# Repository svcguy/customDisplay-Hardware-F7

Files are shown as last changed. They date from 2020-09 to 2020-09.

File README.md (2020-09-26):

A custom display development PCB targeted to be compatible with STM32CubeMX and TouchGFX.  
Based on the STM32F767 MCU with 128Mbit external SDRAM, 512Mbit external QSPI flash.
PCB is designed to be compatible with JLCPCB's SMT service.

More to come!
Work in progress!

Changelog:
Rev A0 -    inital design.  Sent to fab
Rev B1 -    PCB changes -       move traces too close to PCB edge
                                change C23 footprint to 0805 (bom consolidation)
                                move some dimensions to B.Fab layer
            Schematic changes - change C23 footprint to 0805 (bom consolidation)
                                update some footprint properties to "virtual"
            General changes -   Generate PDF of schematic and top and bot assembly drawings

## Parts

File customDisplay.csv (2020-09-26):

Comment | Designator | Footprint | LCSC | Digikey | LCSC
0.1uF | C14,C25,C1,C2,C3,C4,C5,C6,C7,C8,C9,C15,C16,C17,C18,C19,C20,C21,C22,C10,C12,C33,C34,C35,C36,C37,C38,C39,C40,C41,C42,C43,C44,C46,C49,C51,C52 | jlcpcb_smt:C_0402_1005Metric |  | 1276-1004-1-ND | C1525
4.7uF | C23,C50 | jlcpcb_smt:C_0805_2012Metric |  | 490-10481-1-ND | C19666
1uF | C24,C11,C13,C32,C45 | jlcpcb_smt:C_0402_1005Metric |  | 490-10017-1-ND | C52923
2.2uF | C26,C27,C48,C47,C53,C54 | jlcpcb_smt:C_0603_1608Metric |  | 399-7886-1-ND | C23630
15pF | C28,C29 | jlcpcb_smt:C_0402_1005Metric |  | 399-8947-1-ND | C1548
30pF | C30,C31 | jlcpcb_smt:C_0402_1005Metric |  | 311-1666-1-ND | C1570
LED0 | D1 | jlcpcb_smt:LED_0603_1608Metric |  | 160-1447-1-ND | C2286
LED1 | D2 | jlcpcb_smt:LED_0603_1608Metric |  | 160-1448-1-ND | C72038
LED2 | D3 | jlcpcb_smt:LED_0603_1608Metric |  | 160-1446-1-ND | C72043
B5819W | D4 | Diode_SMD:D_SOD-123 |  | B5819W-TPMSCT-ND | C8598
Fiducial | FID1,FID2,FID3,FID4,FID5 | Fiducial:Fiducial_1mm_Mask2mm |  | DNP | DNP
4-40 | H1,H2,H3,H4 | MountingHole:MountingHole_3.2mm_M3 |  | DNP | DNP
STDC14 | J1 | Custom_KICAD:STDC14_BOX |  | 1175-1630-ND | DNP
B2B_TOP | J3,J2 | Custom_KICAD:FX6A-040P-0.8SV |  | H123465-ND | DNP
LCD | J4 | Custom_KICAD:FH12A-40S-0.5SH_REVERSE_PIN_NUMBERING |  | HFK140CT-ND | C262686
TOUCH | J5 | Connector_FFC-FPC:Hirose_FH12-6S-0.5SH_1x06-1MP_P0.50mm_Horizontal |  | HFJ106CT-ND | C262287
USB_B_Micro | J6 | Connector_USB:USB_Micro-B_Amphenol_10103594-0001LF_Horizontal |  | 609-4050-1-ND | C428495
5V_IN | J7 | Connector_PinHeader_2.54mm:PinHeader_1x02_P2.54mm_Vertical |  | DNP | DNP
STDC14_TAG | J8 | Connector:Tag-Connect_TC2070-IDC-FP_2x07_P1.27mm_Vertical |  | DNP | DNP
BEAD | L1,L2,L4 | jlcpcb_smt:L_0805_2012Metric |  | 587-1932-1-ND | C1015
4.7uH | L3 | Custom_KICAD:MWSA0402 |  | 490-10858-1-ND | C408337
COMMON_MODE | L5 | jlcpcb_smt:COMMON_MODE_FILTER_0805 |  | 490-5137-1-ND | C54888
220 | R1,R2,R3 | jlcpcb_smt:R_0402_1005Metric |  | 311-220LRCT-ND | C25091
10k | R5,R4,R10 | jlcpcb_smt:R_0402_1005Metric |  | 311-10.0KLRCT-ND | C25744
4.7k | R6,R7 | jlcpcb_smt:R_0402_1005Metric |  | 311-4.7KLRCT-ND | C25900
10R | R8,R9 | jlcpcb_smt:R_1206_3216Metric |  | RNCP1206FTD10R0CT-ND | C17903
TACT | SW2,SW1 | jlcpcb_smt:TS_1187A |  | 450-2133-1-ND | C318889
ToolingHole | TH1,TH2,TH3 | jlcpcb_smt:JLC_TOOLING_HOLE |  | DNP | DNP
VCP_RX | TP1 | TestPoint:TestPoint_THTPad_1.0x1.0mm_Drill0.5mm |  | DNP | DNP
VCP_TX | TP2 | TestPoint:TestPoint_THTPad_1.0x1.0mm_Drill0.5mm |  | DNP | DNP
I2C_SDA | TP3 | TestPoint:TestPoint_THTPad_1.0x1.0mm_Drill0.5mm |  | DNP | DNP
I2C_SCL | TP4 | TestPoint:TestPoint_THTPad_1.0x1.0mm_Drill0.5mm |  | DNP | DNP
VDD | TP5 | TestPoint:TestPoint_THTPad_1.0x1.0mm_Drill0.5mm |  | DNP | DNP
GND | TP7,TP6 | TestPoint:TestPoint_THTPad_1.0x1.0mm_Drill0.5mm |  | DNP | DNP
GND | TP8 | Custom_KICAD:H9001-01 |  | 952-1450-ND | DNP
STM32F767BGTx | U1 | Package_QFP:LQFP-208_28x28mm_P0.5mm |  | 497-16634-ND | C129277
MT48LC4M32B2TG | U2 | Custom_KICAD:TSOP_II-86-400mill |  | 706-1272-ND | C108951
TSC2007 | U3 | Package_SO:HTSSOP-16-1EP_4.4x5mm_P0.65mm_EP3x3mm |  | 296-27124-1-ND | C38398
TPS61169 | U4 | Custom_KICAD:SC70 |  | 296-40821-1-ND | C71045
MT25QL512ABB | U5 | Custom_KICAD:W-PDFN-8 |  | 557-1786-ND | C88868
USBLC6-2SC6 | U6,U7 | Package_TO_SOT_SMD:SOT-23-6 |  | 497-5235-1-ND | C7519
AMS1117-3.3 | U8 | Package_TO_SOT_SMD:SOT-223-3_TabPin2 |  | 497-1242-1-ND | C6186
32.768kHz | X1 | jlcpcb_smt:Crystal_SMD_3215-2Pin_3.2x1.5mm |  | SER4103CT-ND | C32346
25MHz | X2 | Crystal:Crystal_SMD_3225-4Pin_3.2x2.5mm |  | 2388-SXT32418AA07-25.000MTR-ND | C9006

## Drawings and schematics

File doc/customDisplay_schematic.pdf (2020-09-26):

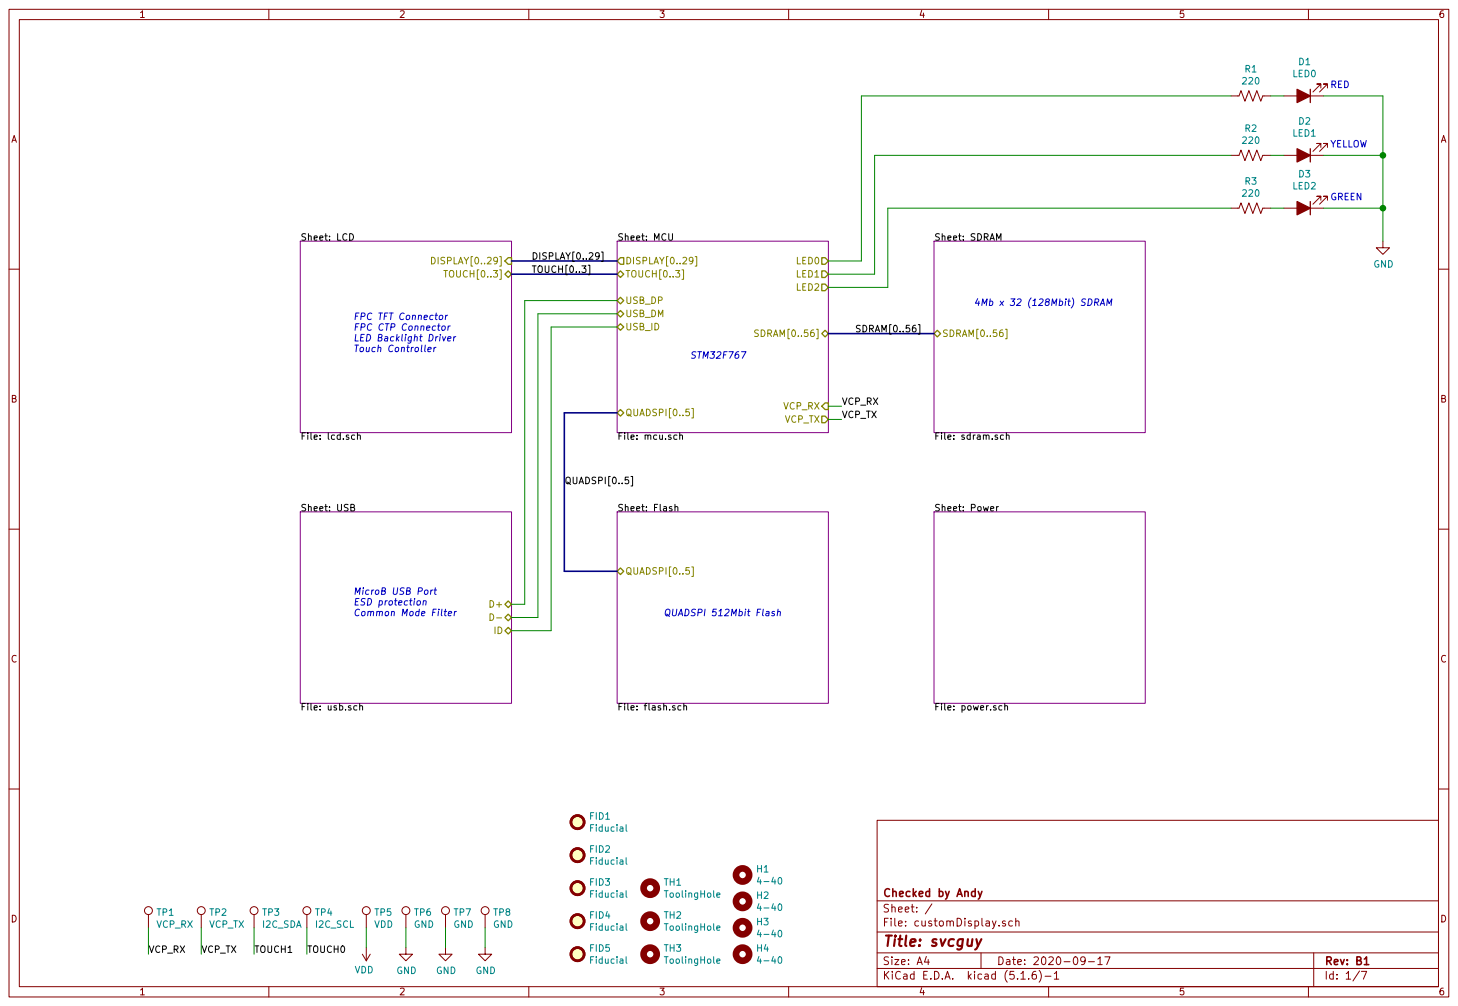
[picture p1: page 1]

Sheet: Flash File: flash.sch QUADSPI[0..5] Sheet: LCD

File: sdram.sch SDRAM[0..56] Sheet: MCU

QUADSPI 512Mbit Flash MicroB USB Port ESD protection Common Mode Filter FPC TFT Connector FPC CTP Connector LED Backlight Driver Touch Controller

Sheet: Power File: power.sch Sheet: USB

File: customDisplay.sch Sheet: / Checked by Andy

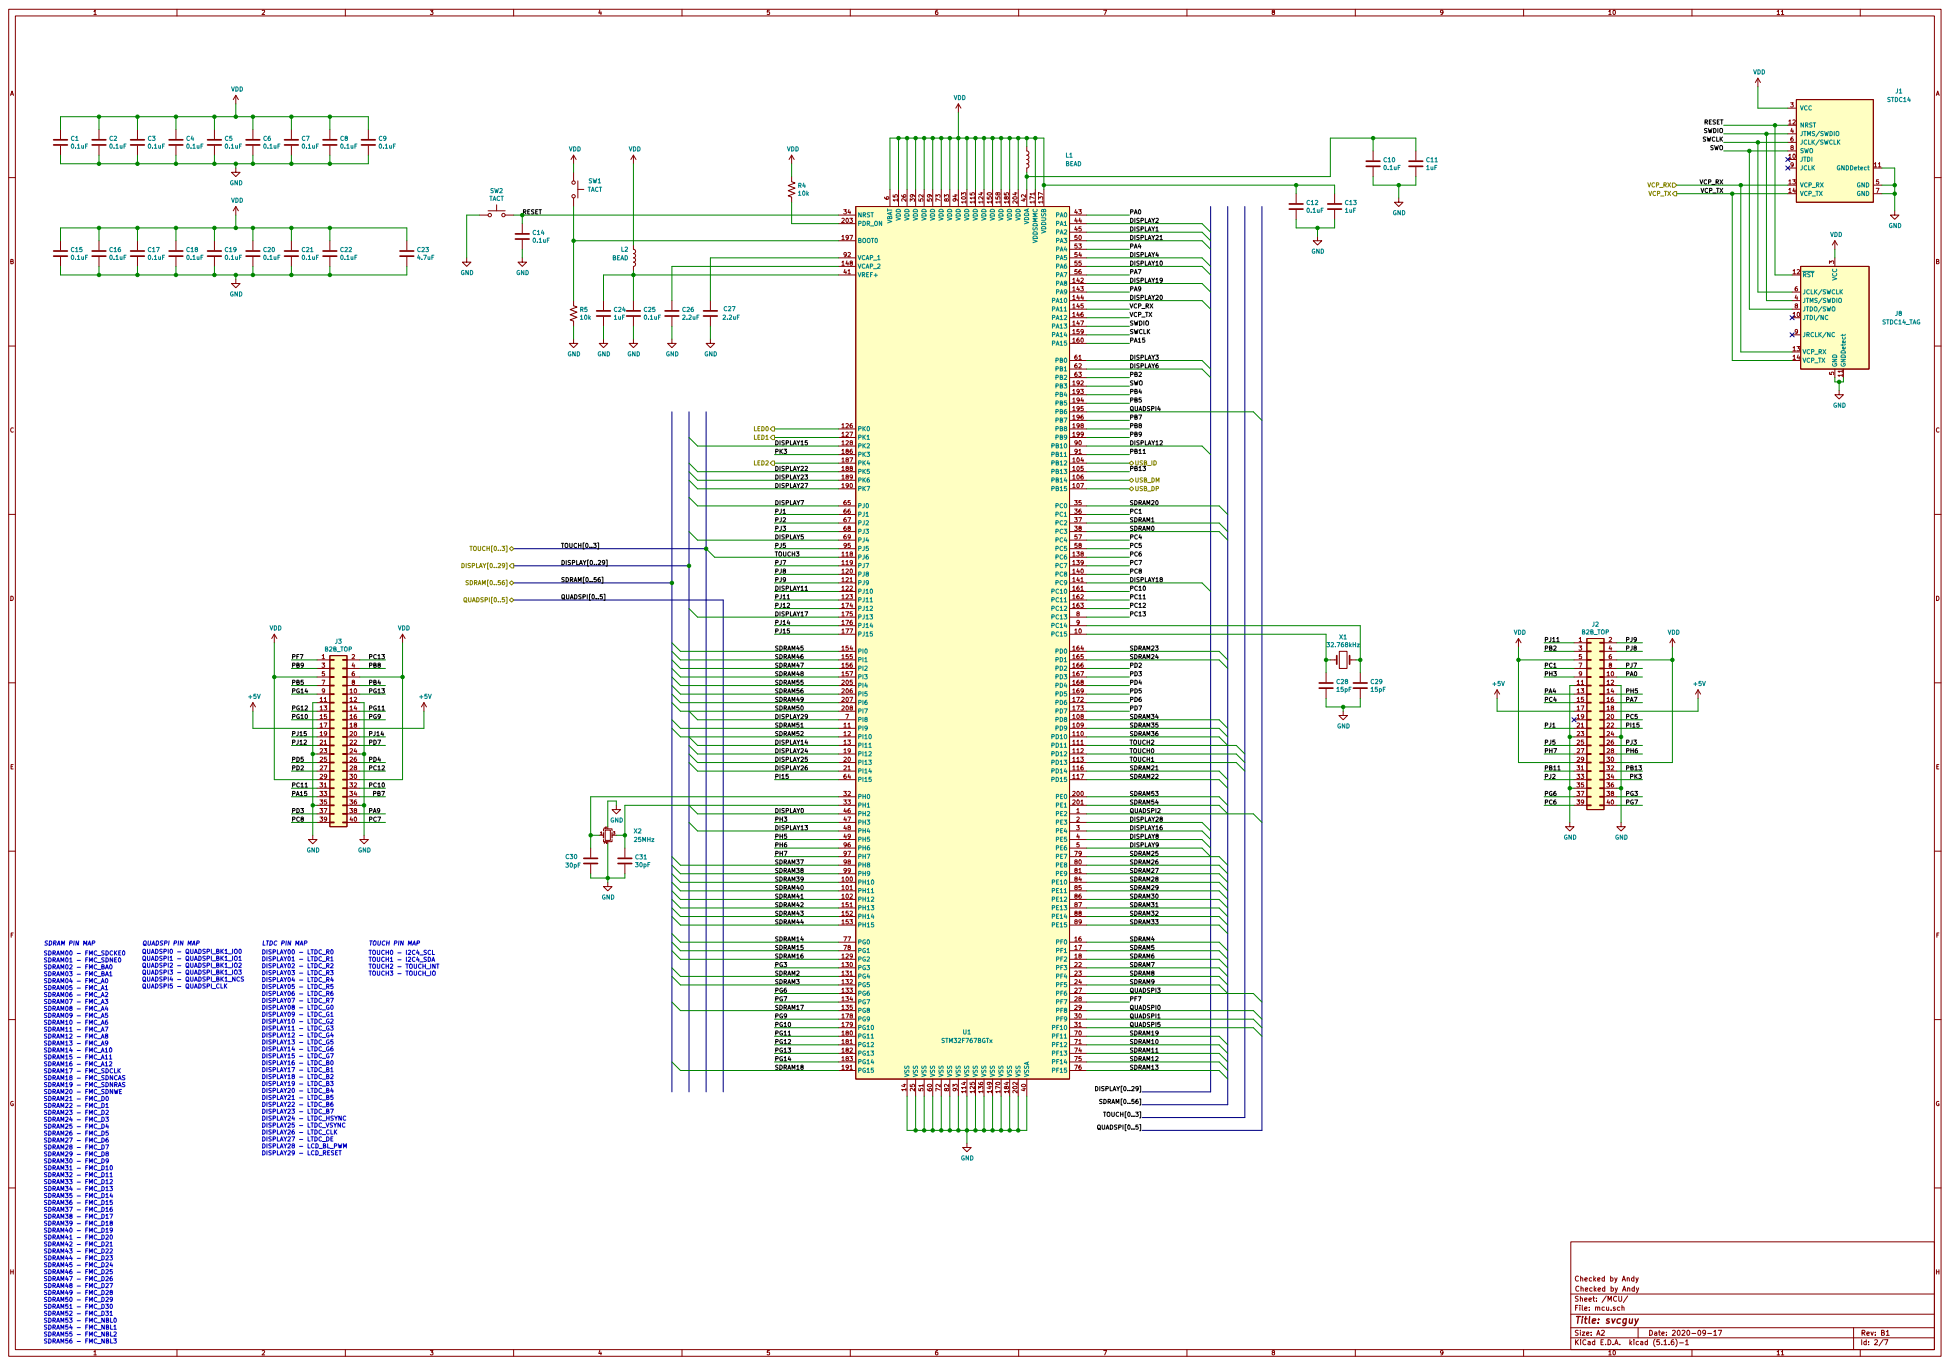
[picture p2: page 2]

File: mcu.sch Sheet: /MCU/ Checked by Andy

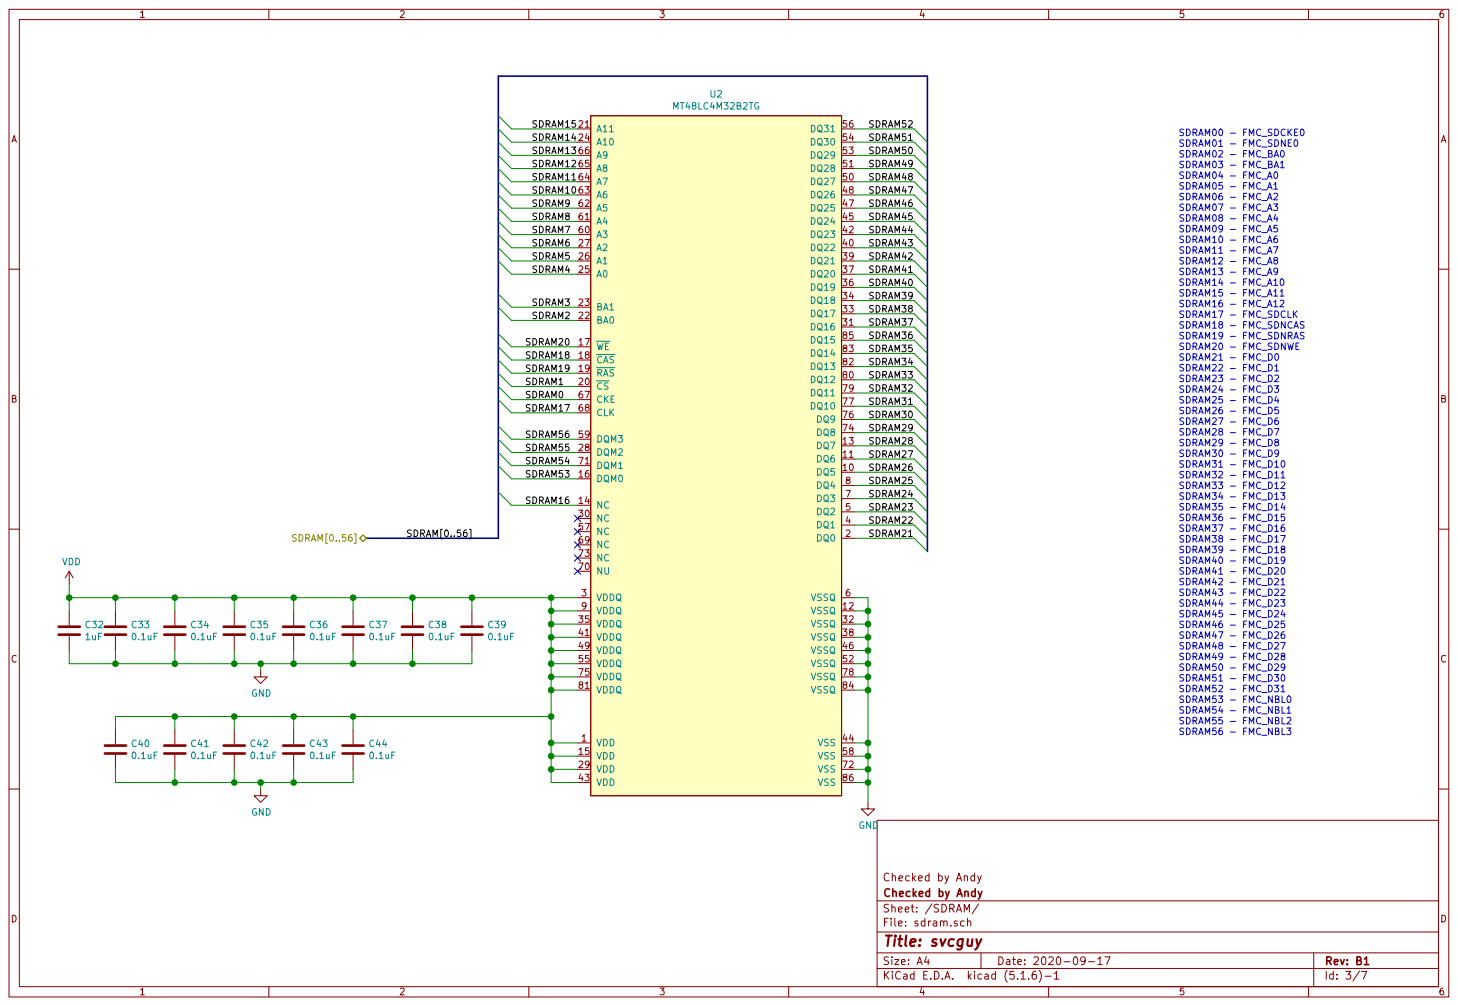
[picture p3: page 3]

File: sdram.sch Sheet: /SDRAM/ Checked by Andy

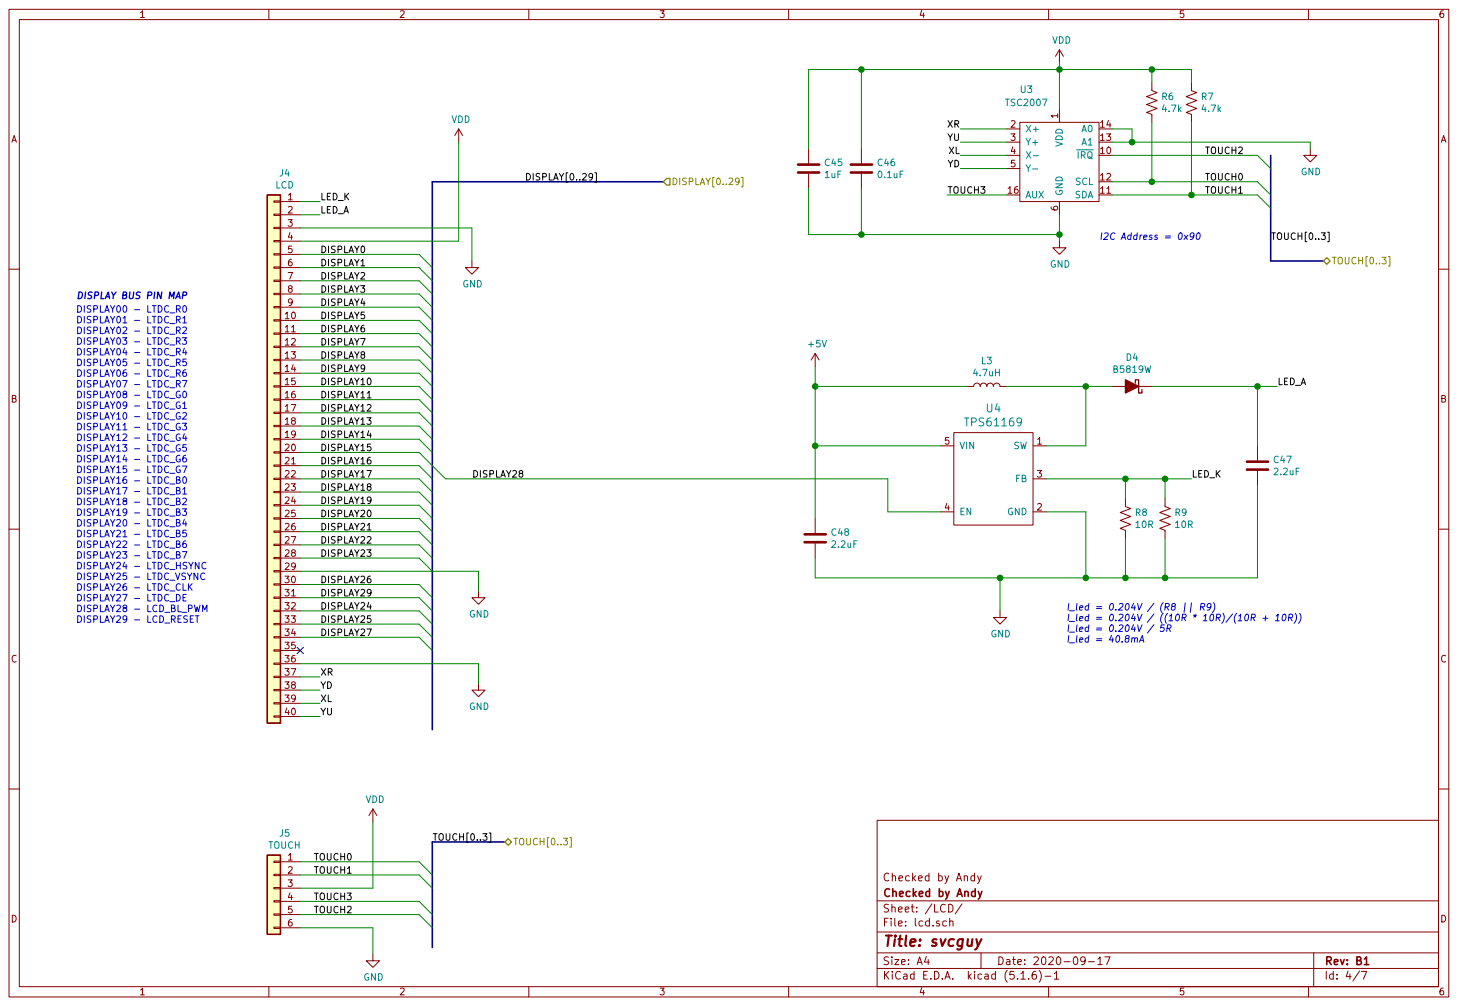
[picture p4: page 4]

I2C Address = 0x90 DISPLAY BUS PIN MAP

Checked by Andy
File: lcd.sch Sheet: /LCD/ Checked by Andy

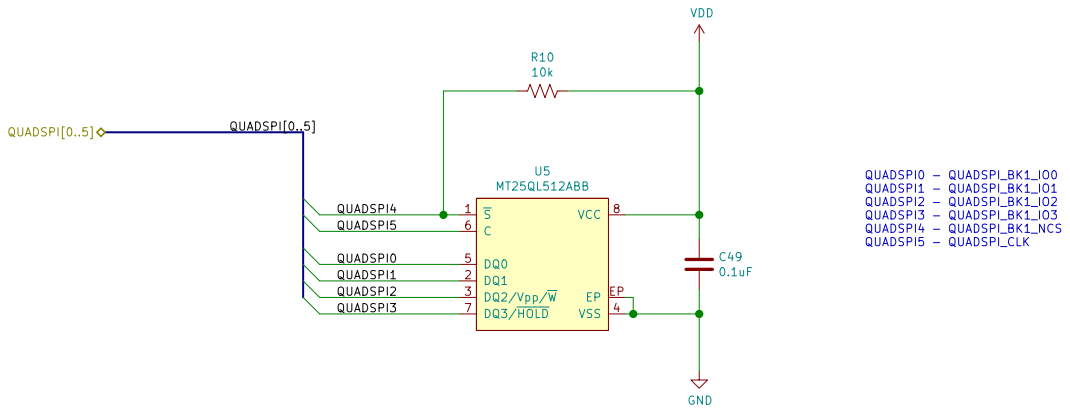
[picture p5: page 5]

Checked by Andy
File: flash.sch Sheet: /Flash/ Checked by Andy

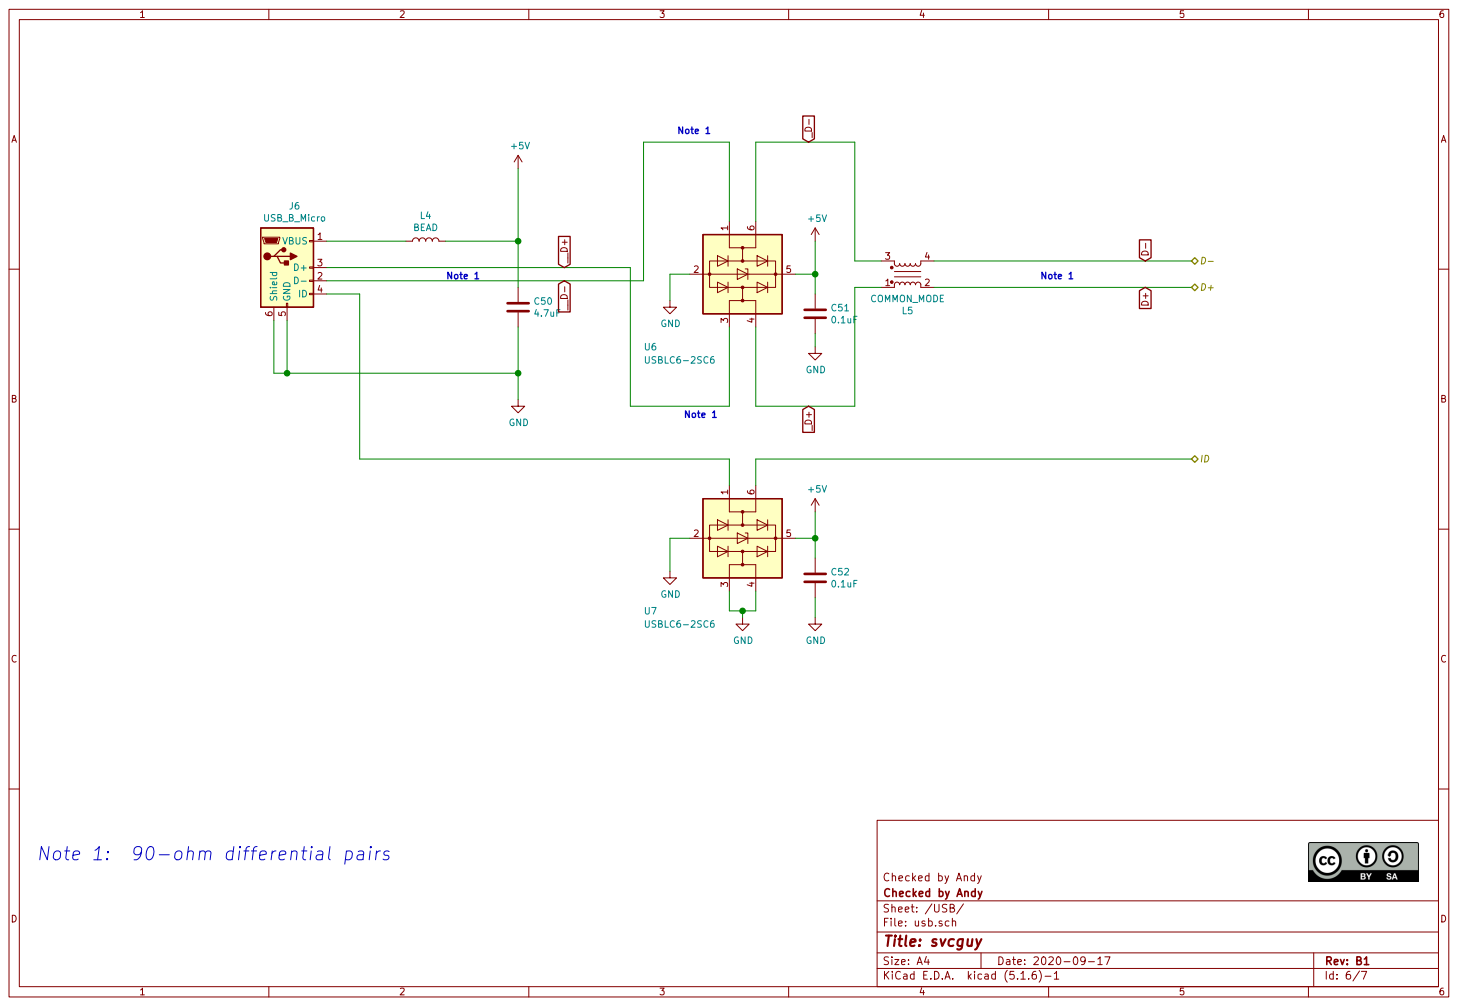
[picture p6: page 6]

Checked by Andy GND

File: usb.sch Sheet: /USB/ Checked by Andy

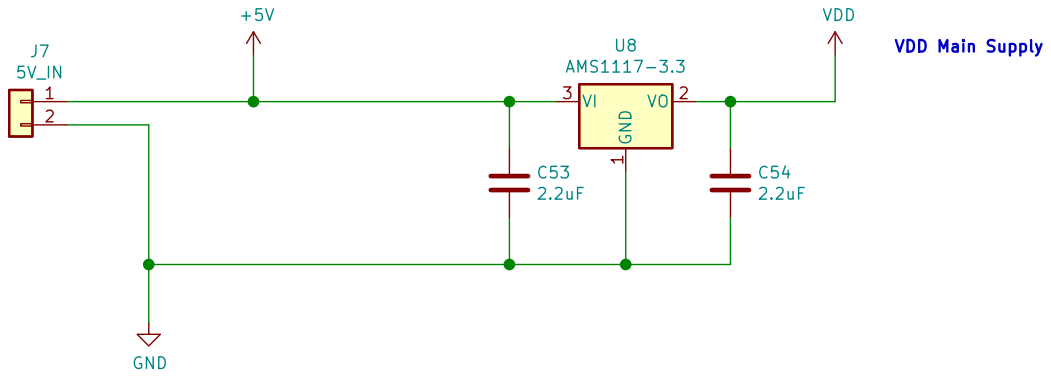
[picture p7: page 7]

File: power.sch Sheet: /Power/ Checked by Andy

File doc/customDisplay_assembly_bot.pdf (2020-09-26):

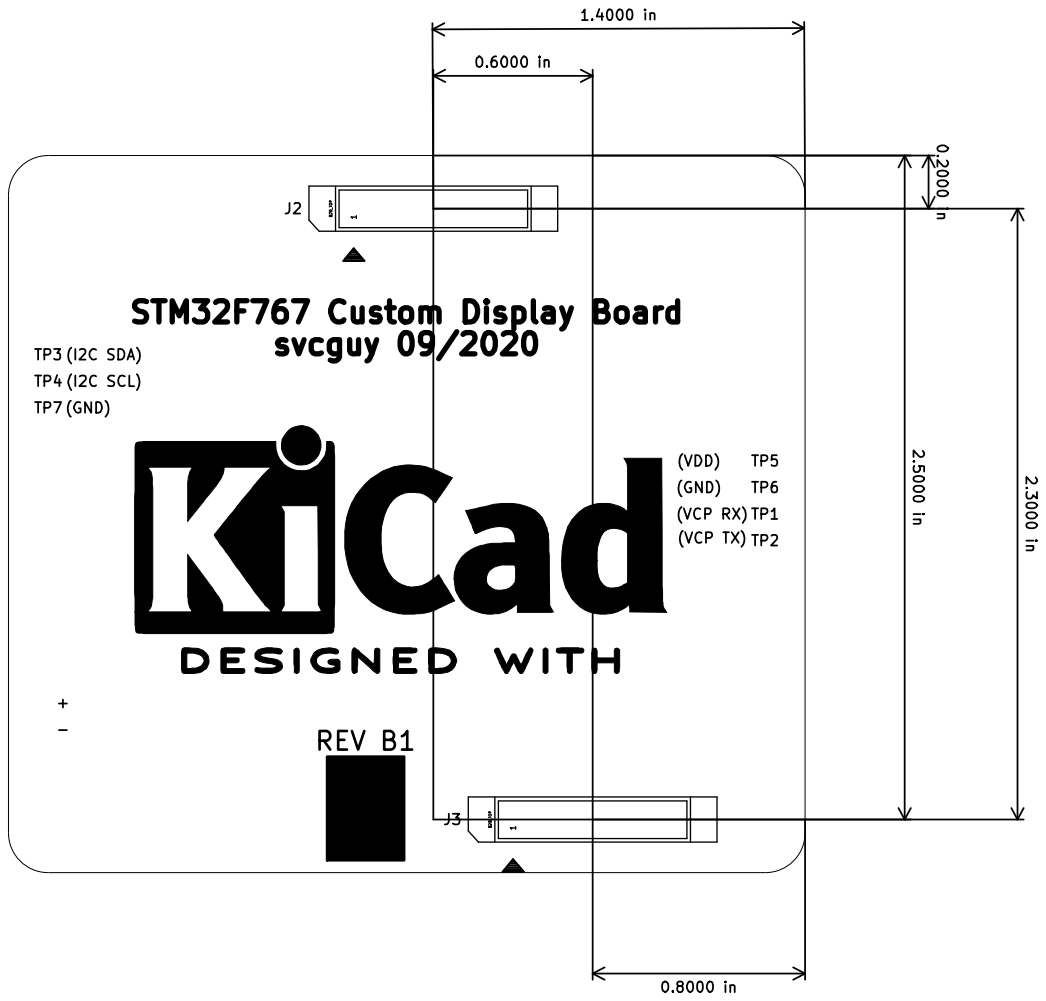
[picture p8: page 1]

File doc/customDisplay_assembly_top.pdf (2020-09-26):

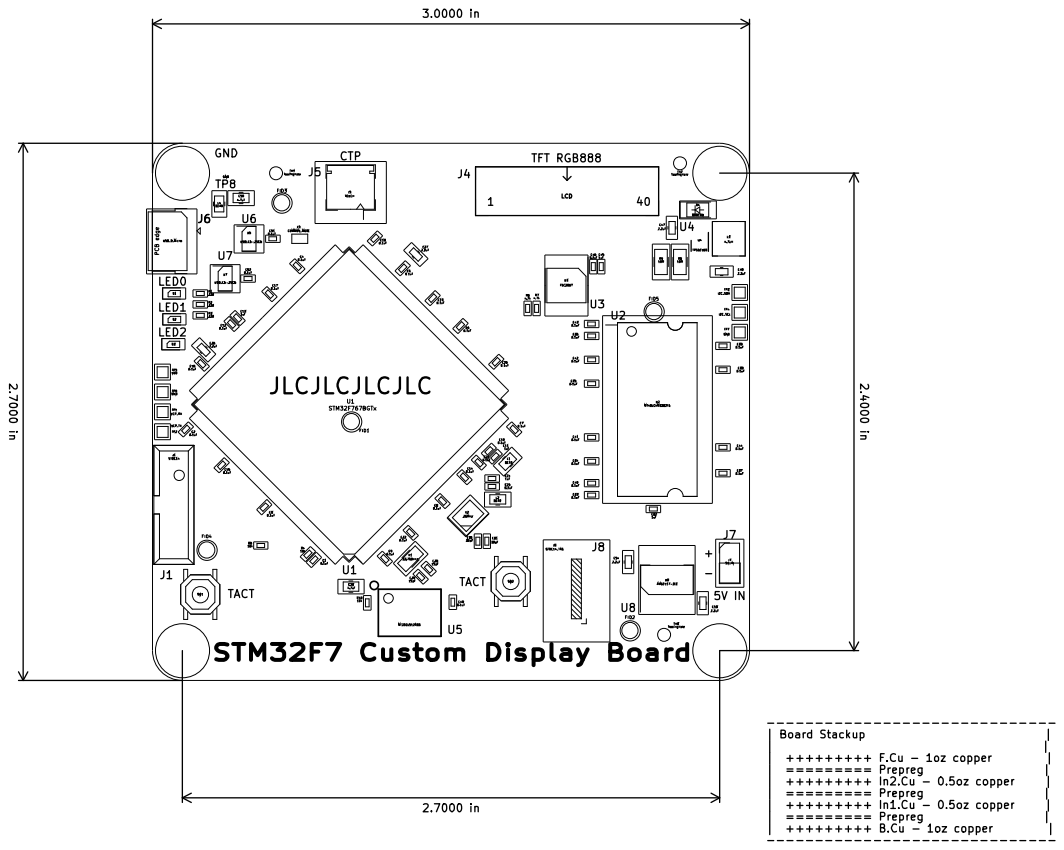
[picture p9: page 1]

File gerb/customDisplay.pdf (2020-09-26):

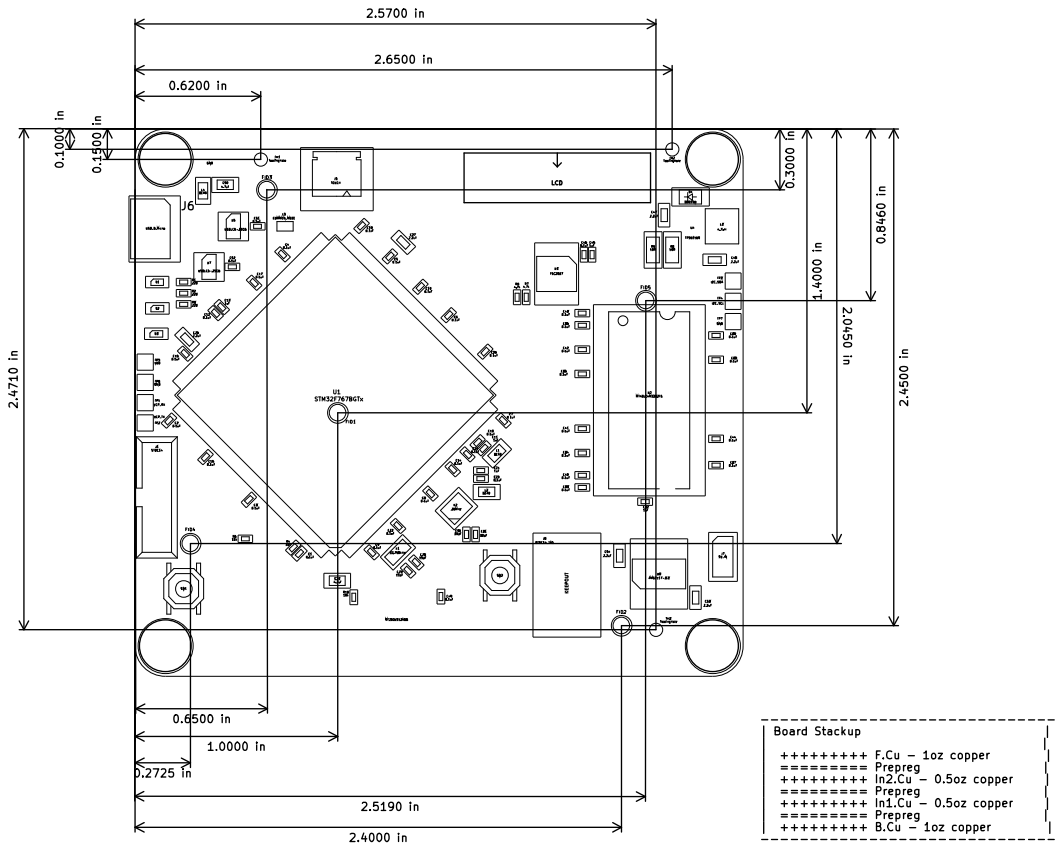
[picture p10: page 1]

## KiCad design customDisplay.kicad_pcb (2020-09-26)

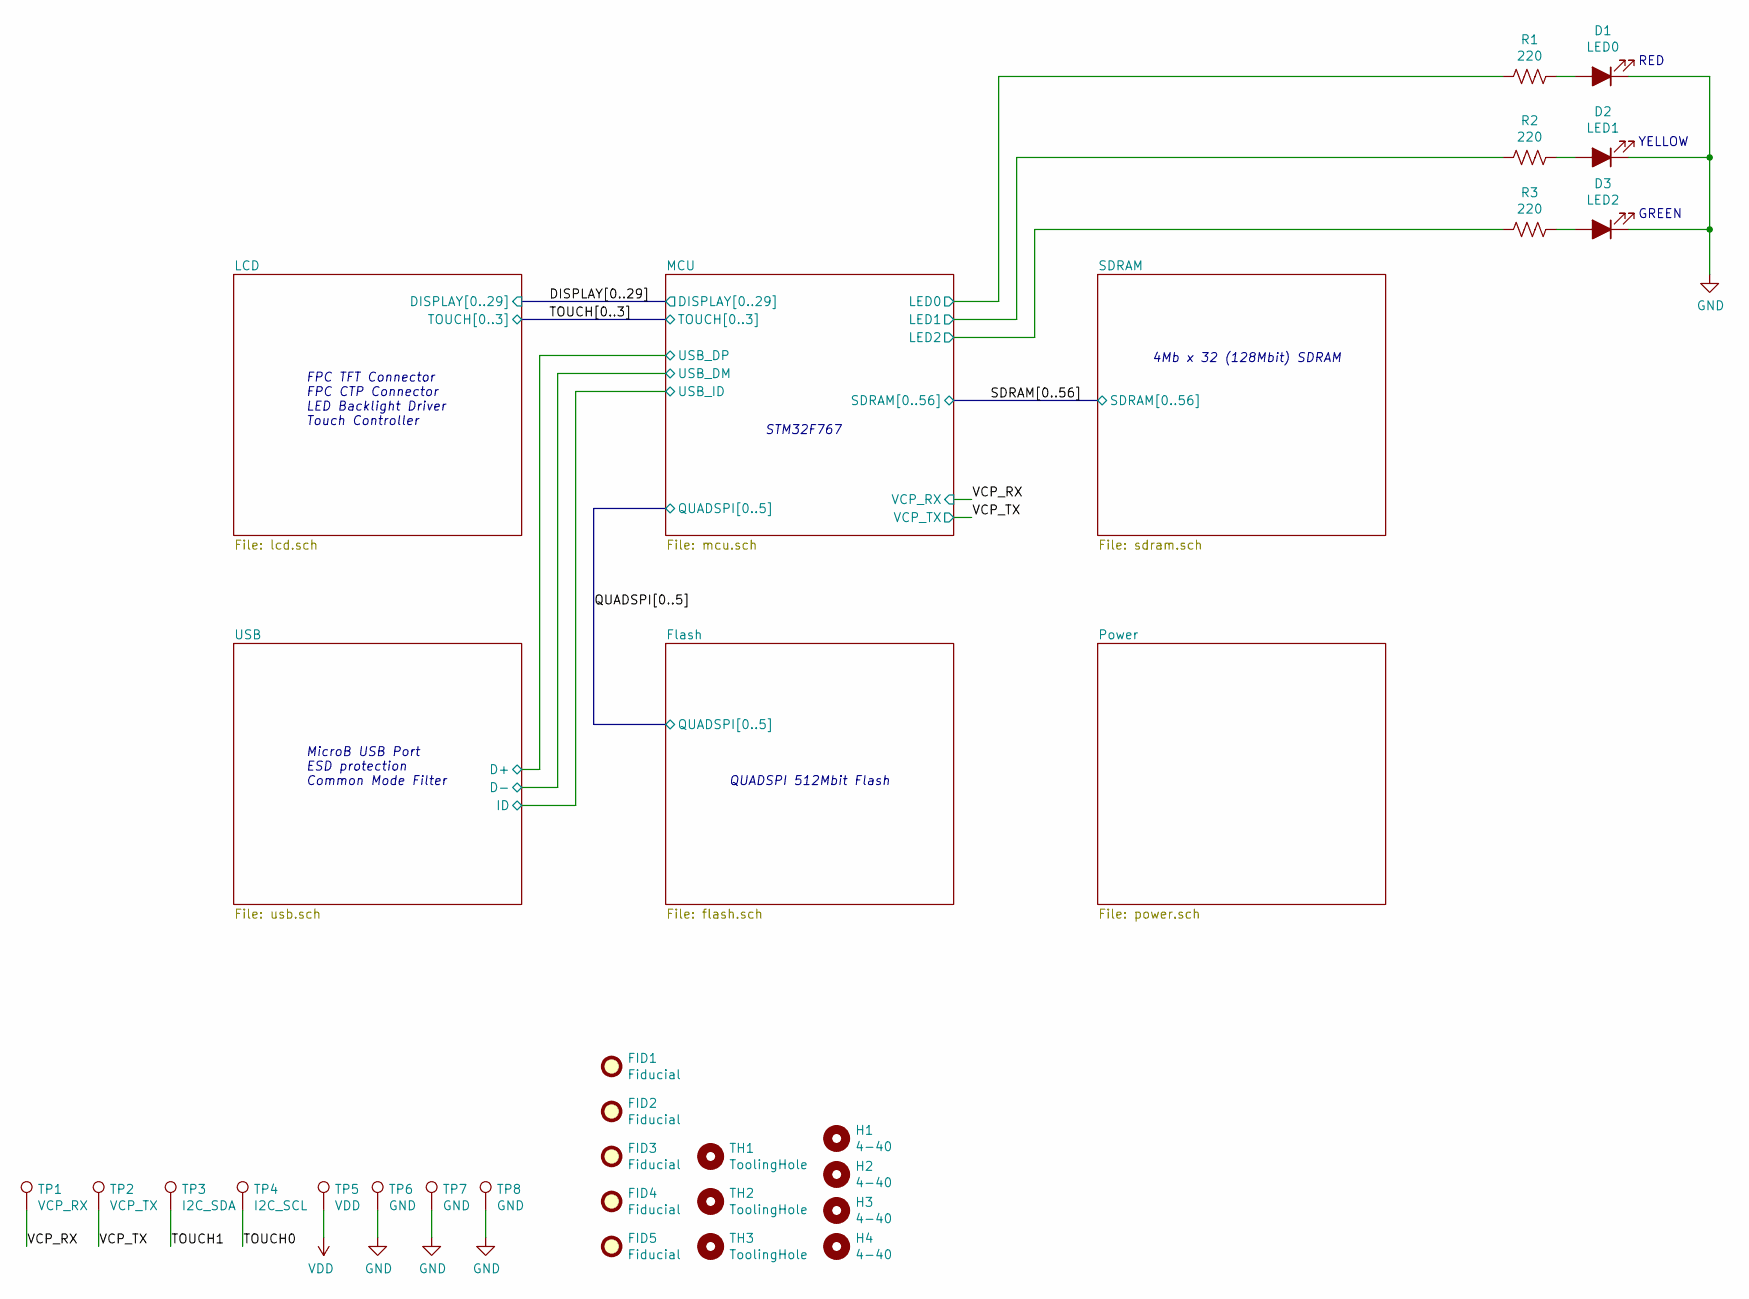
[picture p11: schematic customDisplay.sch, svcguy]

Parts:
D1: LED0; LED_0603_1608Metric; LCSC C2286
D2: LED1; LED_0603_1608Metric; LCSC C72038
D3: LED2; LED_0603_1608Metric; LCSC C72043
FID1, FID2, FID3, FID4, FID5: Fiducial; Fiducial_1mm_Mask2mm; Digikey DNP
H1, H2, H3, H4: 4-40; MountingHole_3.2mm_M3; LCSC DNP
R1, R2, R3: 220; R_0402_1005Metric; LCSC C25091
TH1, TH2, TH3: ToolingHole; JLC_TOOLING_HOLE; Digikey DNP
TP1: VCP_RX; TestPoint_THTPad_1.0x1.0mm_Drill0.5mm; LCSC DNP
TP2: VCP_TX; TestPoint_THTPad_1.0x1.0mm_Drill0.5mm; LCSC DNP
TP3: I2C_SDA; TestPoint_THTPad_1.0x1.0mm_Drill0.5mm; LCSC DNP
TP4: I2C_SCL; TestPoint_THTPad_1.0x1.0mm_Drill0.5mm; LCSC DNP
TP5: VDD; TestPoint_THTPad_1.0x1.0mm_Drill0.5mm; LCSC DNP
TP6, TP7: GND; TestPoint_THTPad_1.0x1.0mm_Drill0.5mm; LCSC DNP
TP8: GND; H9001-01; LCSC DNP

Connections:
/MCU/LED0: R1.2; also elsewhere on the board
/MCU/LED1: R2.2; also elsewhere on the board
/MCU/LED2: R3.2; also elsewhere on the board
/TOUCH0: TP4.1; also elsewhere on the board
/TOUCH1: TP3.1; also elsewhere on the board
/VCP_RX: TP1.1; also elsewhere on the board
/VCP_TX: TP2.1; also elsewhere on the board
GND: D1.1 (K), D2.1 (K), D3.1 (K), TP6.1, TP7.1, TP8.1; also elsewhere on the board
unnamed: D1.2 (A), R1.1
unnamed: D2.2 (A), R2.1
unnamed: D3.2 (A), R3.1
VDD: TP5.1; also elsewhere on the board

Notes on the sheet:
RED
YELLOW
GREEN
FPC TFT Connector FPC CTP Connector LED Backlight Driver Touch Controller
MicroB USB Port ESD protection Common Mode Filter
QUADSPI 512Mbit Flash
4Mb x 32 (128Mbit) SDRAM
STM32F767

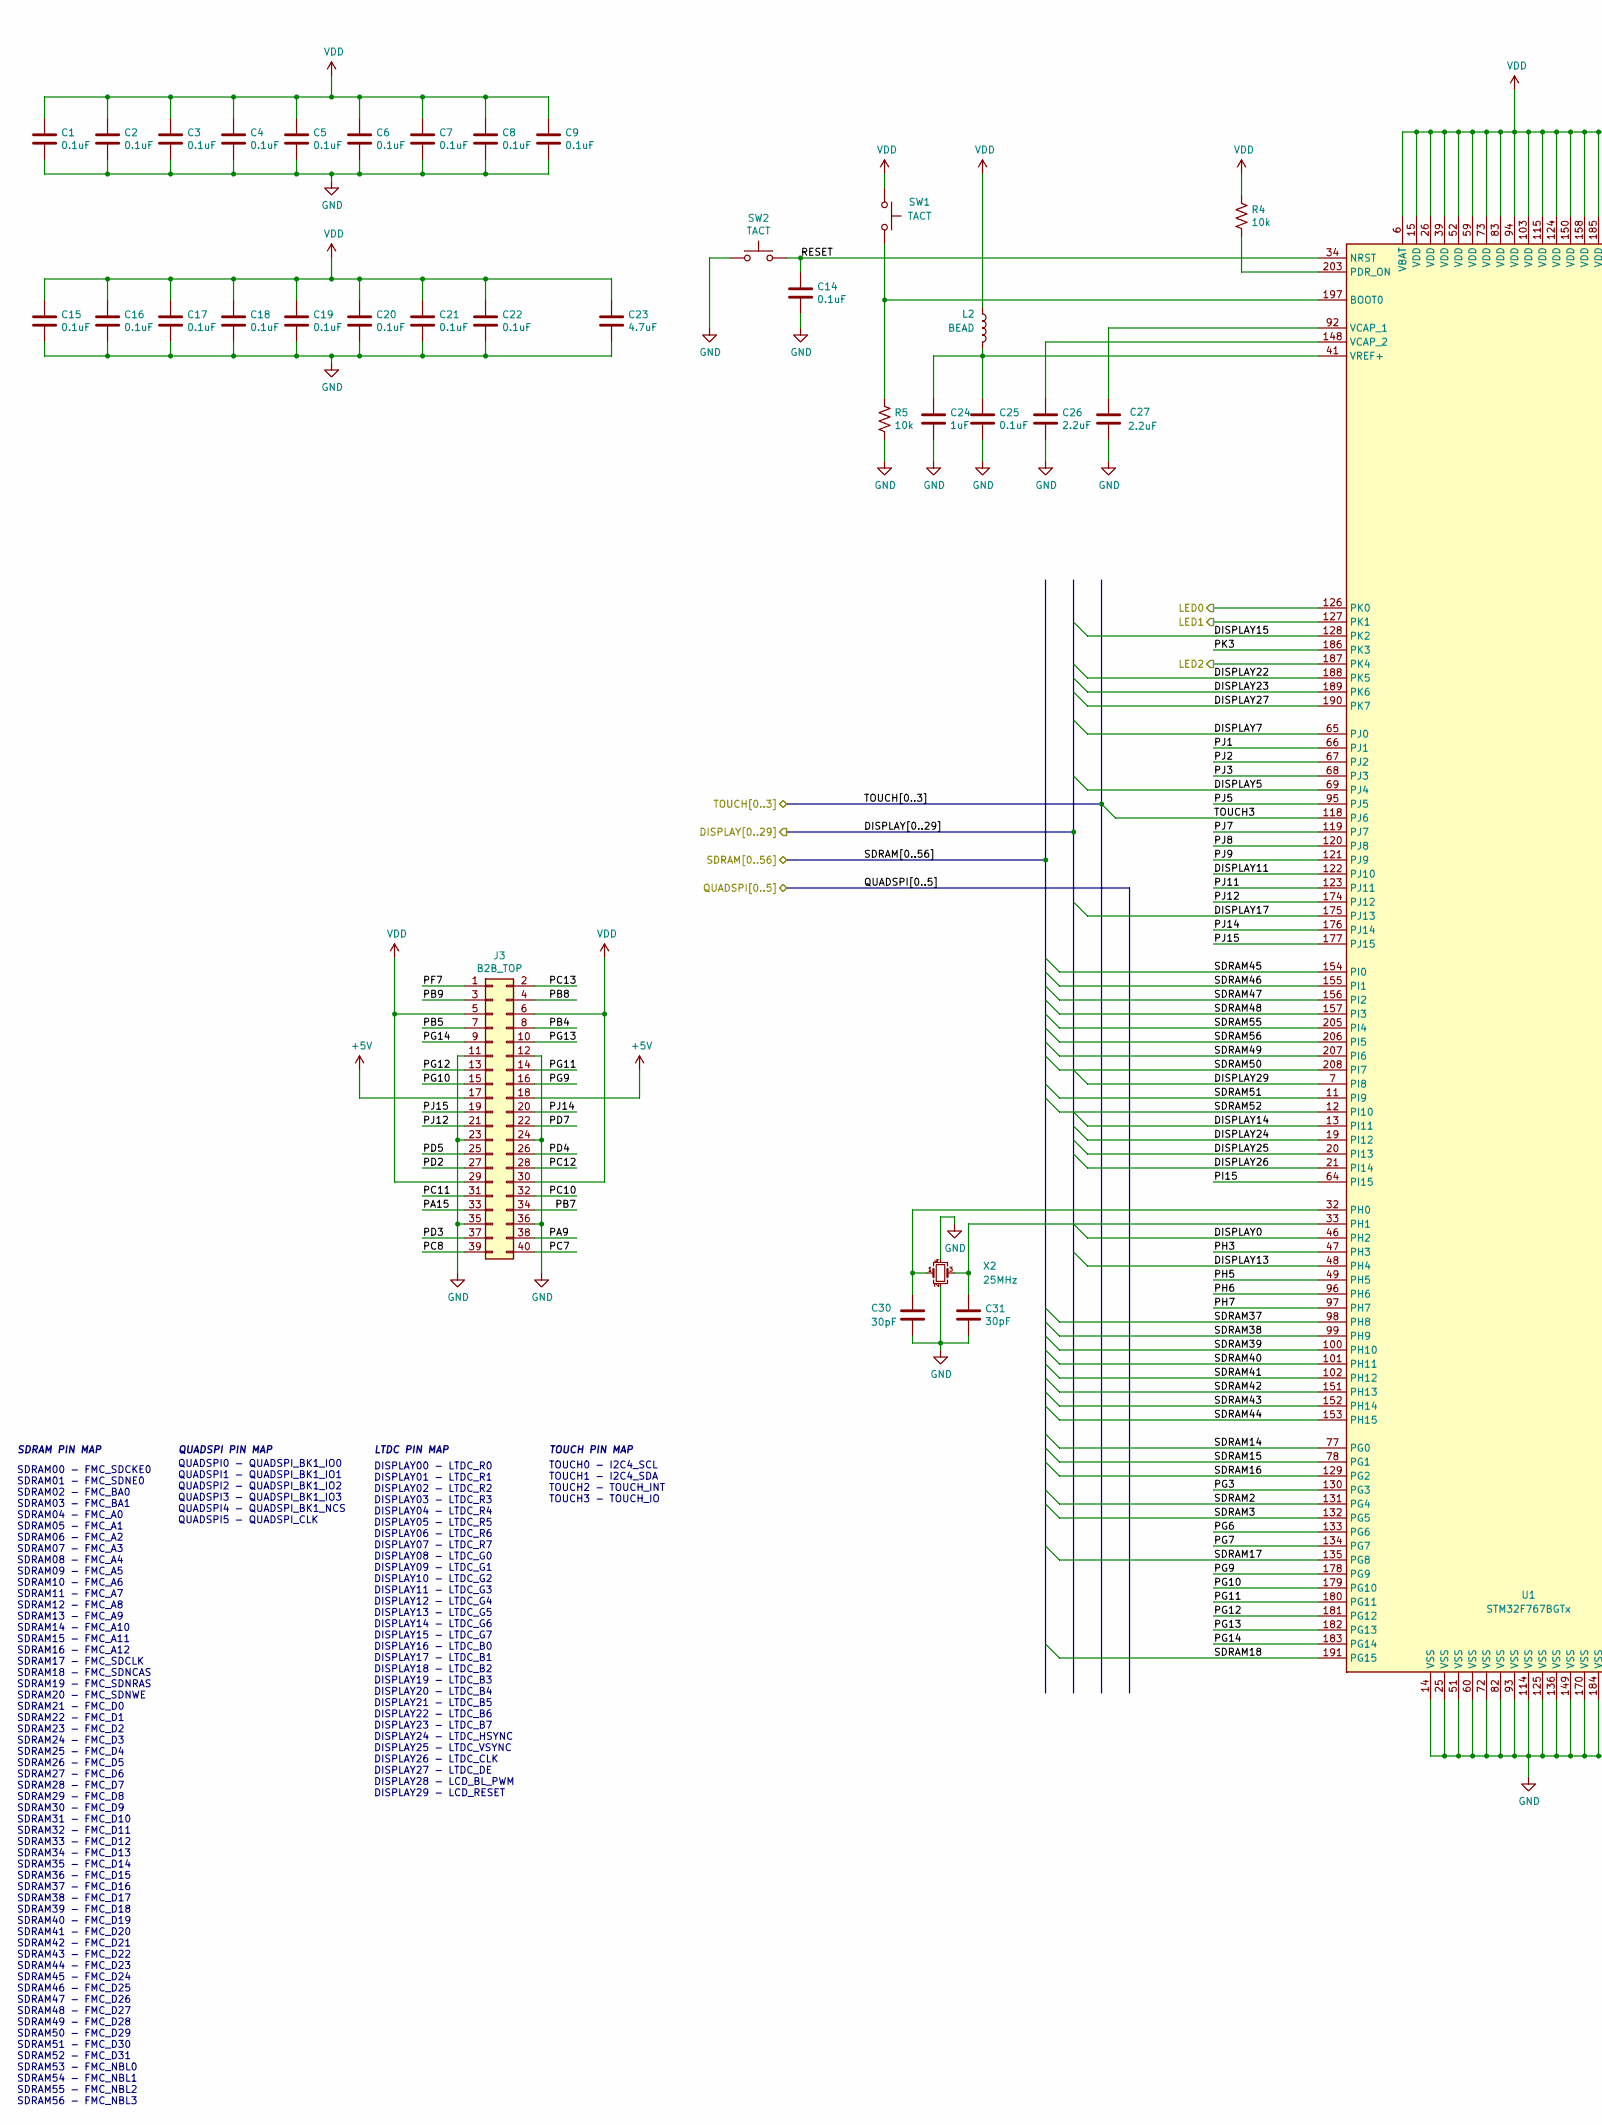
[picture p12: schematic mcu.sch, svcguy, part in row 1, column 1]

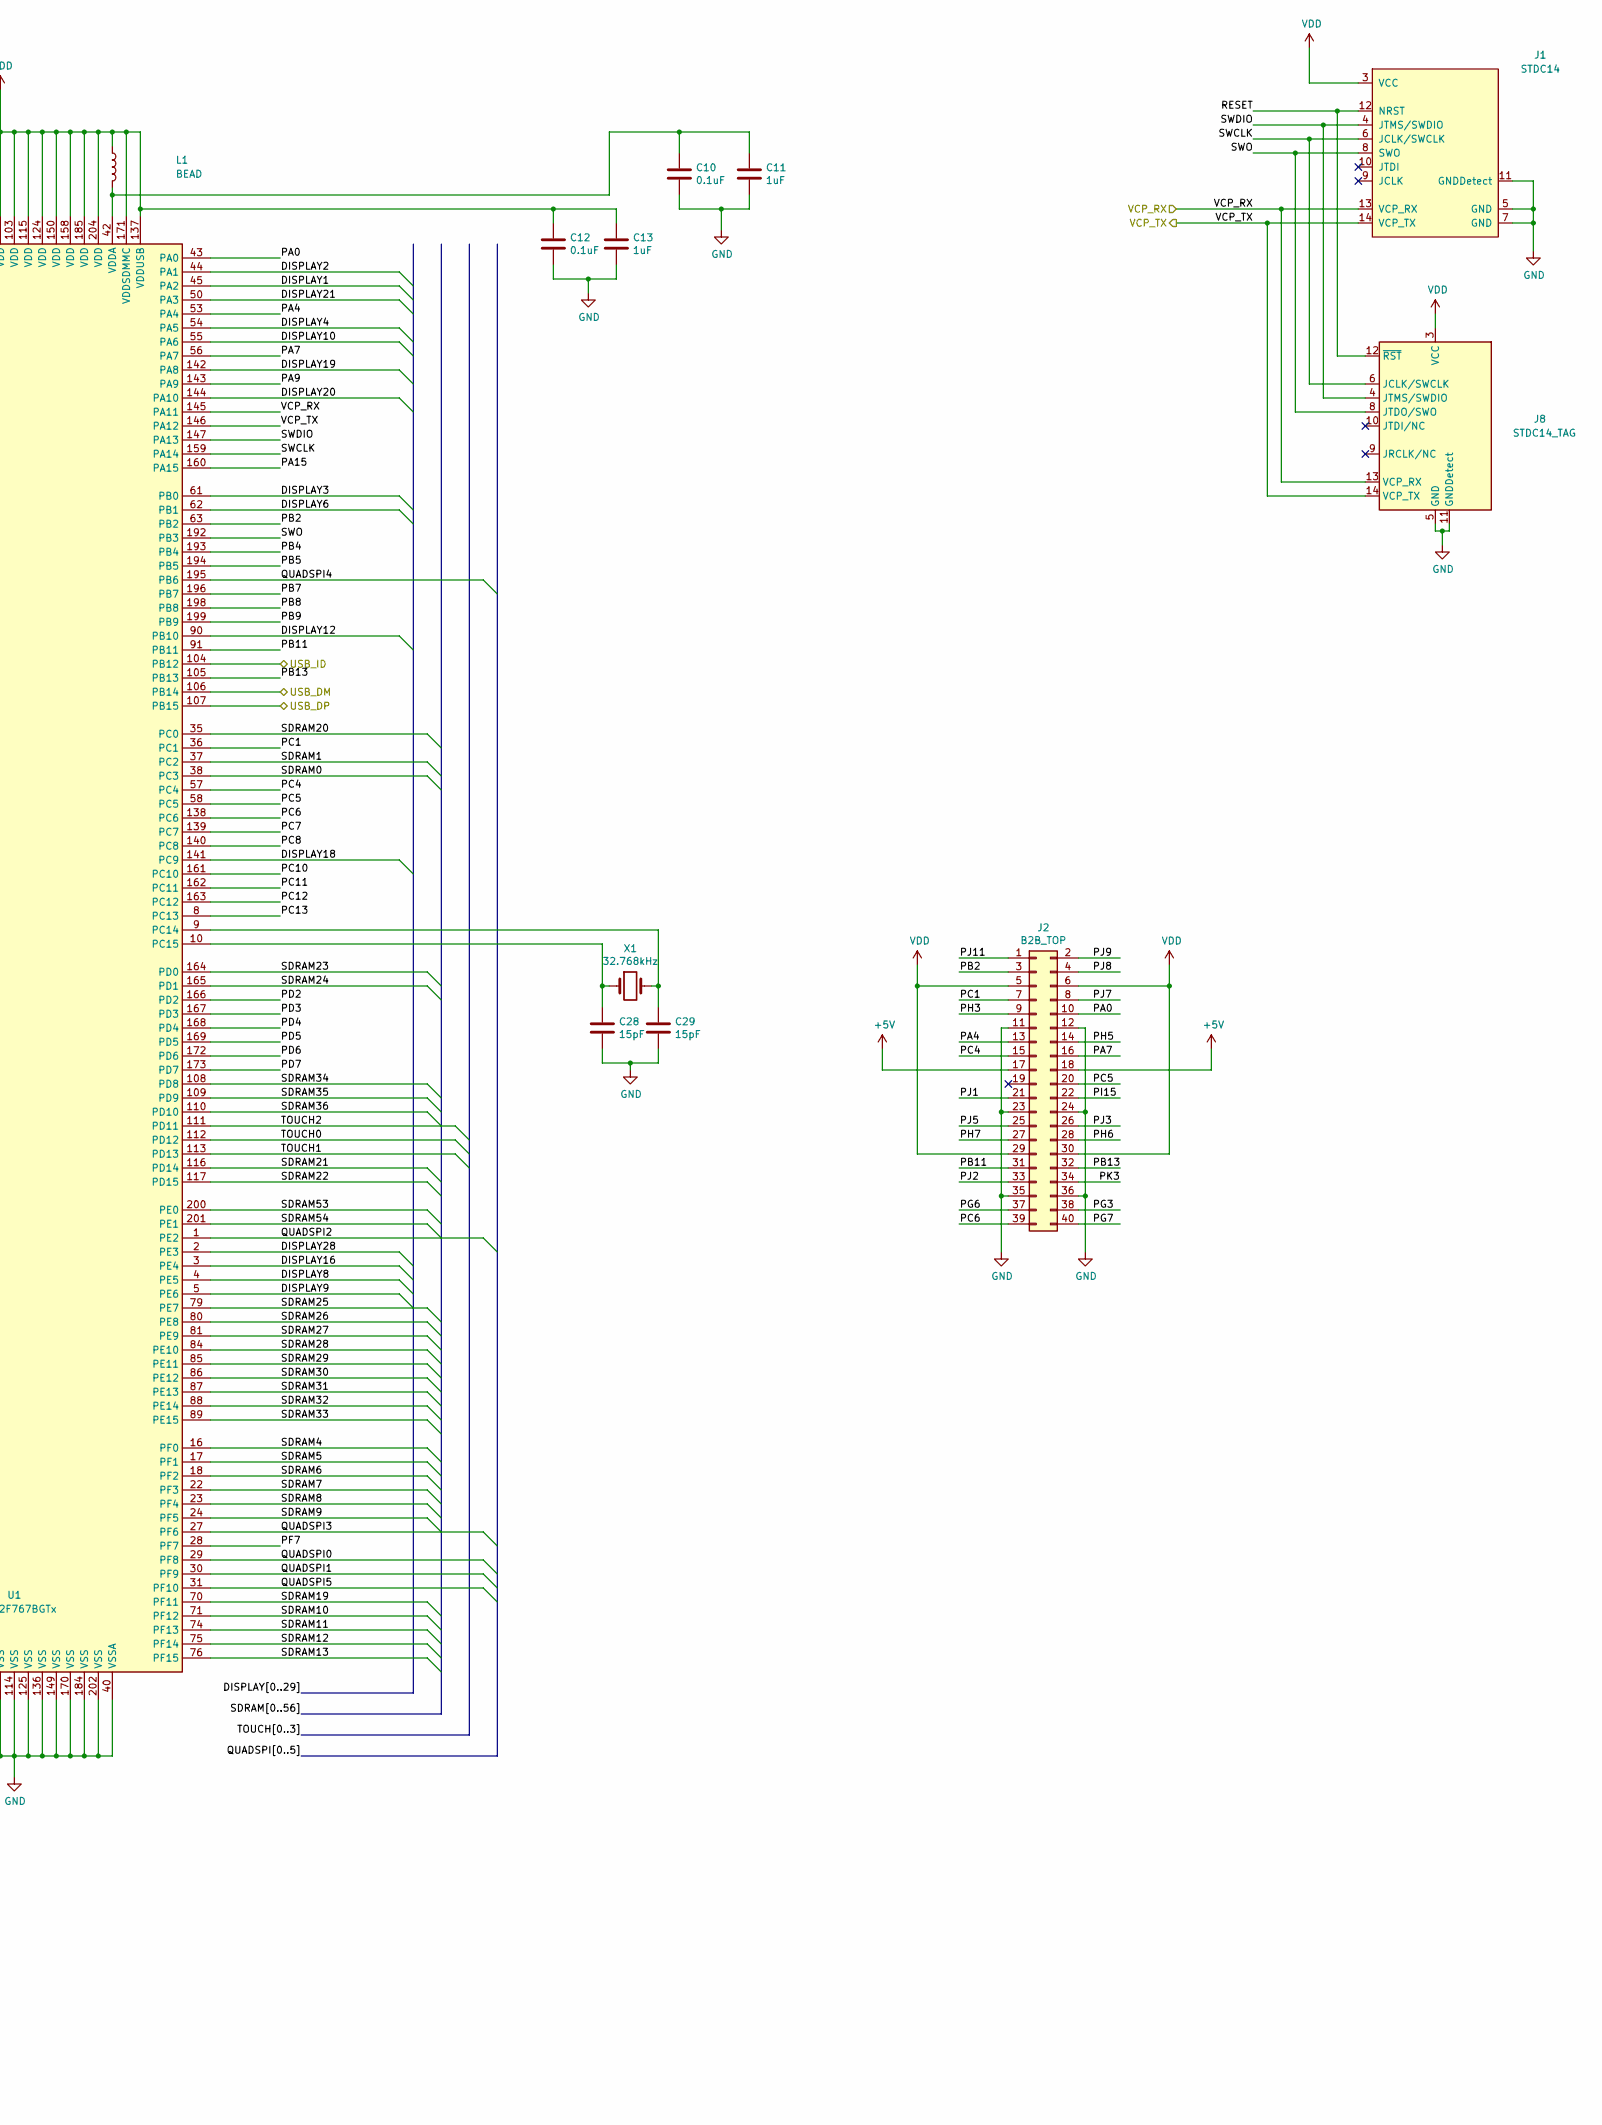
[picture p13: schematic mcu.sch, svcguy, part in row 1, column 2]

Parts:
C1, C2, C3, C4, C5, C6, C7, C8, C9, C10, C12, C14, C15, C16, C17, C18, C19, C20, C21, C22, C25: 0.1uF; C_0402_1005Metric; LCSC C1525
C11, C13, C24: 1uF; C_0402_1005Metric; LCSC C52923
C23: 4.7uF; C_0805_2012Metric; LCSC C19666
C26, C27: 2.2uF; C_0603_1608Metric; LCSC C23630
C28, C29: 15pF; C_0402_1005Metric; LCSC C1548
C30, C31: 30pF; C_0402_1005Metric; LCSC C1570
J1: STDC14; STDC14_BOX; LCSC DNP
J2, J3: B2B_TOP; FX6A-040P-0.8SV; LCSC DNP
J8: STDC14_TAG; Tag-Connect_TC2070-IDC-FP_2x07_P1.27mm_Vertical; LCSC DNP
L1, L2: BEAD; L_0805_2012Metric; LCSC C1015
R4, R5: 10k; R_0402_1005Metric; LCSC C25744
SW1, SW2: TACT; TS_1187A; LCSC C318889
U1: STM32F767BGTx; LQFP-208_28x28mm_P0.5mm; LCSC C129277
X1: 32.768kHz; Crystal_SMD_3215-2Pin_3.2x1.5mm; LCSC C32346
X2: 25MHz; Crystal_SMD_3225-4Pin_3.2x2.5mm; LCSC C9006

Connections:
+5V: J2.17, J2.18, J3.17, J3.18; also elsewhere on the board
/Flash/QUADSPI0: U1.29 (PF8); also elsewhere on the board
/Flash/QUADSPI1: U1.30 (PF9); also elsewhere on the board
/Flash/QUADSPI2: U1.1 (PE2); also elsewhere on the board
/Flash/QUADSPI3: U1.27 (PF6); also elsewhere on the board
/Flash/QUADSPI4: U1.195 (PB6); also elsewhere on the board
/Flash/QUADSPI5: U1.31 (PF10); also elsewhere on the board
/LCD/DISPLAY0: U1.46 (PH2); also elsewhere on the board
/LCD/DISPLAY1: U1.45 (PA2); also elsewhere on the board
/LCD/DISPLAY2: U1.44 (PA1); also elsewhere on the board
/LCD/DISPLAY3: U1.61 (PB0); also elsewhere on the board
/LCD/DISPLAY4: U1.54 (PA5); also elsewhere on the board
/LCD/DISPLAY5: U1.69 (PJ4); also elsewhere on the board
/LCD/DISPLAY6: U1.62 (PB1); also elsewhere on the board
/LCD/DISPLAY7: U1.65 (PJ0); also elsewhere on the board
/LCD/DISPLAY8: U1.4 (PE5); also elsewhere on the board
/LCD/DISPLAY9: U1.5 (PE6); also elsewhere on the board
/LCD/DISPLAY10: U1.55 (PA6); also elsewhere on the board
/LCD/DISPLAY11: U1.122 (PJ10); also elsewhere on the board
/LCD/DISPLAY12: U1.90 (PB10); also elsewhere on the board
/LCD/DISPLAY13: U1.48 (PH4); also elsewhere on the board
/LCD/DISPLAY14: U1.13 (PI11); also elsewhere on the board
/LCD/DISPLAY15: U1.128 (PK2); also elsewhere on the board
/LCD/DISPLAY16: U1.3 (PE4); also elsewhere on the board
/LCD/DISPLAY17: U1.175 (PJ13); also elsewhere on the board
/LCD/DISPLAY18: U1.141 (PC9); also elsewhere on the board
/LCD/DISPLAY19: U1.142 (PA8); also elsewhere on the board
/LCD/DISPLAY20: U1.144 (PA10); also elsewhere on the board
/LCD/DISPLAY21: U1.50 (PA3); also elsewhere on the board
/LCD/DISPLAY22: U1.188 (PK5); also elsewhere on the board
/LCD/DISPLAY23: U1.189 (PK6); also elsewhere on the board
/LCD/DISPLAY24: U1.19 (PI12); also elsewhere on the board
/LCD/DISPLAY25: U1.20 (PI13); also elsewhere on the board
/LCD/DISPLAY26: U1.21 (PI14); also elsewhere on the board
/LCD/DISPLAY27: U1.190 (PK7); also elsewhere on the board
/LCD/DISPLAY28: U1.2 (PE3); also elsewhere on the board
/LCD/DISPLAY29: U1.7 (PI8); also elsewhere on the board
/LCD/TOUCH2: U1.111 (PD11); also elsewhere on the board
/LCD/TOUCH3: U1.118 (PJ6); also elsewhere on the board
/MCU/LED0: U1.126 (PK0); also elsewhere on the board
/MCU/LED1: U1.127 (PK1); also elsewhere on the board
/MCU/LED2: U1.187 (PK4); also elsewhere on the board
/MCU/PA0: J2.10, U1.43 (PA0)
/MCU/PA4: J2.13, U1.53 (PA4)
/MCU/PA7: J2.16, U1.56 (PA7)
/MCU/PA9: J3.38, U1.143 (PA9)
/MCU/PA15: J3.33, U1.160 (PA15)
/MCU/PB2: J2.3, U1.63 (PB2)
/MCU/PB4: J3.8, U1.193 (PB4)
/MCU/PB5: J3.7, U1.194 (PB5)
/MCU/PB7: J3.34, U1.196 (PB7)
/MCU/PB8: J3.4, U1.198 (PB8)
/MCU/PB9: J3.3, U1.199 (PB9)
/MCU/PB11: J2.31, U1.91 (PB11)
/MCU/PB13: J2.32, U1.105 (PB13)
/MCU/PC1: J2.7, U1.36 (PC1)
/MCU/PC4: J2.15, U1.57 (PC4)
/MCU/PC5: J2.20, U1.58 (PC5)
/MCU/PC6: J2.39, U1.138 (PC6)
/MCU/PC7: J3.40, U1.139 (PC7)
/MCU/PC8: J3.39, U1.140 (PC8)
/MCU/PC10: J3.32, U1.161 (PC10)
/MCU/PC11: J3.31, U1.162 (PC11)
/MCU/PC12: J3.28, U1.163 (PC12)
/MCU/PC13: J3.2, U1.8 (PC13)
/MCU/PD2: J3.27, U1.166 (PD2)
/MCU/PD3: J3.37, U1.167 (PD3)
/MCU/PD4: J3.26, U1.168 (PD4)
/MCU/PD5: J3.25, U1.169 (PD5)
/MCU/PD7: J3.22, U1.173 (PD7)
/MCU/PF7: J3.1, U1.28 (PF7)
/MCU/PG3: J2.38, U1.130 (PG3)
/MCU/PG6: J2.37, U1.133 (PG6)
/MCU/PG7: J2.40, U1.134 (PG7)
/MCU/PG9: J3.16, U1.178 (PG9)
/MCU/PG10: J3.15, U1.179 (PG10)
/MCU/PG11: J3.14, U1.180 (PG11)
/MCU/PG12: J3.13, U1.181 (PG12)
/MCU/PG13: J3.10, U1.182 (PG13)
/MCU/PG14: J3.9, U1.183 (PG14)
/MCU/PH3: J2.9, U1.47 (PH3)
/MCU/PH5: J2.14, U1.49 (PH5)
/MCU/PH6: J2.28, U1.96 (PH6)
/MCU/PH7: J2.27, U1.97 (PH7)
/MCU/PI15: J2.22, U1.64 (PI15)
/MCU/PJ1: J2.21, U1.66 (PJ1)
/MCU/PJ2: J2.33, U1.67 (PJ2)
/MCU/PJ3: J2.26, U1.68 (PJ3)
/MCU/PJ5: J2.25, U1.95 (PJ5)
/MCU/PJ7: J2.8, U1.119 (PJ7)
/MCU/PJ8: J2.4, U1.120 (PJ8)
/MCU/PJ9: J2.2, U1.121 (PJ9)
/MCU/PJ11: J2.1, U1.123 (PJ11)
/MCU/PJ12: J3.21, U1.174 (PJ12)
/MCU/PJ14: J3.20, U1.176 (PJ14)
/MCU/PJ15: J3.19, U1.177 (PJ15)
/MCU/PK3: J2.34, U1.186 (PK3)
/MCU/RESET: C14.1, J1.12 (NRST), J8.12 (~RST), SW2.2, U1.34 (NRST)
/MCU/SDRAM0: U1.38 (PC3); also elsewhere on the board
/MCU/SDRAM1: U1.37 (PC2); also elsewhere on the board
/MCU/SDRAM2: U1.131 (PG4); also elsewhere on the board
/MCU/SDRAM3: U1.132 (PG5); also elsewhere on the board
/MCU/SDRAM4: U1.16 (PF0); also elsewhere on the board
/MCU/SDRAM5: U1.17 (PF1); also elsewhere on the board
/MCU/SDRAM6: U1.18 (PF2); also elsewhere on the board
/MCU/SDRAM7: U1.22 (PF3); also elsewhere on the board
/MCU/SDRAM8: U1.23 (PF4); also elsewhere on the board
/MCU/SDRAM9: U1.24 (PF5); also elsewhere on the board
/MCU/SDRAM10: U1.71 (PF12); also elsewhere on the board
/MCU/SDRAM11: U1.74 (PF13); also elsewhere on the board
/MCU/SDRAM12: U1.75 (PF14); also elsewhere on the board
/MCU/SDRAM13: U1.76 (PF15); also elsewhere on the board
/MCU/SDRAM14: U1.77 (PG0); also elsewhere on the board
/MCU/SDRAM15: U1.78 (PG1); also elsewhere on the board
/MCU/SDRAM16: U1.129 (PG2); also elsewhere on the board
/MCU/SDRAM17: U1.135 (PG8); also elsewhere on the board
/MCU/SDRAM18: U1.191 (PG15); also elsewhere on the board
/MCU/SDRAM19: U1.70 (PF11); also elsewhere on the board
/MCU/SDRAM20: U1.35 (PC0); also elsewhere on the board
/MCU/SDRAM21: U1.116 (PD14); also elsewhere on the board
/MCU/SDRAM22: U1.117 (PD15); also elsewhere on the board
/MCU/SDRAM23: U1.164 (PD0); also elsewhere on the board
/MCU/SDRAM24: U1.165 (PD1); also elsewhere on the board
/MCU/SDRAM25: U1.79 (PE7); also elsewhere on the board
/MCU/SDRAM26: U1.80 (PE8); also elsewhere on the board
/MCU/SDRAM27: U1.81 (PE9); also elsewhere on the board
/MCU/SDRAM28: U1.84 (PE10); also elsewhere on the board
/MCU/SDRAM29: U1.85 (PE11); also elsewhere on the board
/MCU/SDRAM30: U1.86 (PE12); also elsewhere on the board
/MCU/SDRAM31: U1.87 (PE13); also elsewhere on the board
/MCU/SDRAM32: U1.88 (PE14); also elsewhere on the board
/MCU/SDRAM33: U1.89 (PE15); also elsewhere on the board
/MCU/SDRAM34: U1.108 (PD8); also elsewhere on the board
/MCU/SDRAM35: U1.109 (PD9); also elsewhere on the board
/MCU/SDRAM36: U1.110 (PD10); also elsewhere on the board
/MCU/SDRAM37: U1.98 (PH8); also elsewhere on the board
/MCU/SDRAM38: U1.99 (PH9); also elsewhere on the board
/MCU/SDRAM39: U1.100 (PH10); also elsewhere on the board
/MCU/SDRAM40: U1.101 (PH11); also elsewhere on the board
/MCU/SDRAM41: U1.102 (PH12); also elsewhere on the board
/MCU/SDRAM42: U1.151 (PH13); also elsewhere on the board
/MCU/SDRAM43: U1.152 (PH14); also elsewhere on the board
/MCU/SDRAM44: U1.153 (PH15); also elsewhere on the board
/MCU/SDRAM45: U1.154 (PI0); also elsewhere on the board
/MCU/SDRAM46: U1.155 (PI1); also elsewhere on the board
/MCU/SDRAM47: U1.156 (PI2); also elsewhere on the board
/MCU/SDRAM48: U1.157 (PI3); also elsewhere on the board
/MCU/SDRAM49: U1.207 (PI6); also elsewhere on the board
/MCU/SDRAM50: U1.208 (PI7); also elsewhere on the board
/MCU/SDRAM51: U1.11 (PI9); also elsewhere on the board
/MCU/SDRAM52: U1.12 (PI10); also elsewhere on the board
/MCU/SDRAM53: U1.200 (PE0); also elsewhere on the board
/MCU/SDRAM54: U1.201 (PE1); also elsewhere on the board
/MCU/SDRAM55: U1.205 (PI4); also elsewhere on the board
/MCU/SDRAM56: U1.206 (PI5); also elsewhere on the board
/MCU/SWCLK: J1.6 (JCLK/SWCLK), J8.6 (JCLK/SWCLK), U1.159 (PA14)
/MCU/SWDIO: J1.4 (JTMS/SWDIO), J8.4 (JTMS/SWDIO), U1.147 (PA13)
/MCU/SWO: J1.8 (SWO), J8.8 (JTDO/SWO), U1.192 (PB3)
/TOUCH0: U1.112 (PD12); also elsewhere on the board
/TOUCH1: U1.113 (PD13); also elsewhere on the board
/USB/ID: U1.104 (PB12); also elsewhere on the board
/VCP_RX: J1.13 (VCP_RX), J8.13 (VCP_RX), U1.145 (PA11); also elsewhere on the board
/VCP_TX: J1.14 (VCP_TX), J8.14 (VCP_TX), U1.146 (PA12); also elsewhere on the board
D+: U1.107 (PB15); also elsewhere on the board
D-: U1.106 (PB14); also elsewhere on the board
GND: C1.2, C2.2, C3.2, C4.2, C5.2, C6.2, C7.2, C8.2, C9.2, C10.2, C11.2, C12.2, C13.2, C14.2, C15.2, C16.2, C17.2, C18.2, C19.2, C20.2, C21.2, C22.2, C23.2, C24.2, C25.2, C26.2, C27.1, C28.2, C29.2, C30.2, C31.2, J1.5 (GND), J1.7 (GND), J1.11 (GNDDetect), J2.11, J2.12, J2.23, J2.24, J2.35, J2.36, J3.11, J3.12, J3.23, J3.24, J3.35, J3.36, J8.5 (GND), J8.7 (GND), J8.11 (GNDDetect), R5.2, SW2.1, U1.14 (VSS), U1.25 (VSS), U1.40 (VSSA), U1.51 (VSS), U1.60 (VSS), U1.72 (VSS), U1.82 (VSS), U1.93 (VSS), U1.114 (VSS), U1.125 (VSS), U1.136 (VSS), U1.149 (VSS), U1.170 (VSS), U1.184 (VSS), U1.202 (VSS), X2.2, X2.4; also elsewhere on the board
unnamed: C10.1, C11.1, L1.2, U1.42 (VDDA)
unnamed: C24.1, C25.1, L2.2, U1.41 (VREF+)
unnamed: C26.1, U1.148 (VCAP_2)
unnamed: C27.2, U1.92 (VCAP_1)
unnamed: C28.1, U1.10 (PC15), X1.1
unnamed: C29.1, U1.9 (PC14), X1.2
unnamed: C30.1, U1.32 (PH0), X2.1
unnamed: C31.1, U1.33 (PH1), X2.3
unnamed: R4.2, U1.203 (PDR_ON)
unnamed: R5.1, SW1.2, U1.197 (BOOT0)
VDD: C1.1, C2.1, C3.1, C4.1, C5.1, C6.1, C7.1, C8.1, C9.1, C12.1, C13.1, C15.1, C16.1, C17.1, C18.1, C19.1, C20.1, C21.1, C22.1, C23.1, J1.3 (VCC), J2.5, J2.6, J2.29, J2.30, J3.5, J3.6, J3.29, J3.30, J8.3 (VCC), L1.1, L2.1, R4.1, SW1.1, U1.6 (VBAT), U1.15 (VDD), U1.26 (VDD), U1.39 (VDD), U1.52 (VDD), U1.59 (VDD), U1.73 (VDD), U1.83 (VDD), U1.94 (VDD), U1.103 (VDD), U1.115 (VDD), U1.124 (VDD), U1.137 (VDDUSB), U1.150 (VDD), U1.158 (VDD), U1.171 (VDDSDMMC), U1.185 (VDD), U1.204 (VDD); also elsewhere on the board

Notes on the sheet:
SDRAM PIN MAP
SDRAM00 - FMC_SDCKE0 SDRAM01 - FMC_SDNE0 SDRAM02 - FMC_BA0 SDRAM03 - FMC_BA1 SDRAM04 - FMC_A0 SDRAM05 - FMC_A1 SDRAM06 - FMC_A2 SDRAM07 - FMC_A3 SDRAM08 - FMC_A4 SDRAM09 - FMC_A5 SDRAM10 - FMC_A6 SDRAM11 - FMC_A7 SDRAM12 - FMC_A8 SDRAM13 - FMC_A9 SDRAM14 - FMC_A10 SDRAM15 - FMC_A11 SDRAM16 - FMC_A1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
QUADSPI PIN MAP
QUADSPI0 - QUADSPI_BK1_IO0 QUADSPI1 - QUADSPI_BK1_IO1 QUADSPI2 - QUADSPI_BK1_IO2 QUADSPI3 - QUADSPI_BK1_IO3 QUADSPI4 - QUADSPI_BK1_NCS QUADSPI5 - QUADSPI_CLK
DISPLAY00 - LTDC_R0 DISPLAY01 - LTDC_R1 DISPLAY02 - LTDC_R2 DISPLAY03 - LTDC_R3 DISPLAY04 - LTDC_R4 DISPLAY05 - LTDC_R5 DISPLAY06 - LTDC_R6 DISPLAY07 - LTDC_R7 DISPLAY08 - LTDC_G0 DISPLAY09 - LTDC_G1 DISPLAY10 - LTDC_G2 DISPLAY11 - LTDC_G3 DISPLAY12 - LTDC_G4 DISPLAY13 - LTDC_G5 DISPLAY14 - LTDC_G6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
LTDC PIN MAP
TOUCH PIN MAP
TOUCH0 - I2C4_SCL TOUCH1 - I2C4_SDA TOUCH2 - TOUCH_INT TOUCH3 - TOUCH_IO

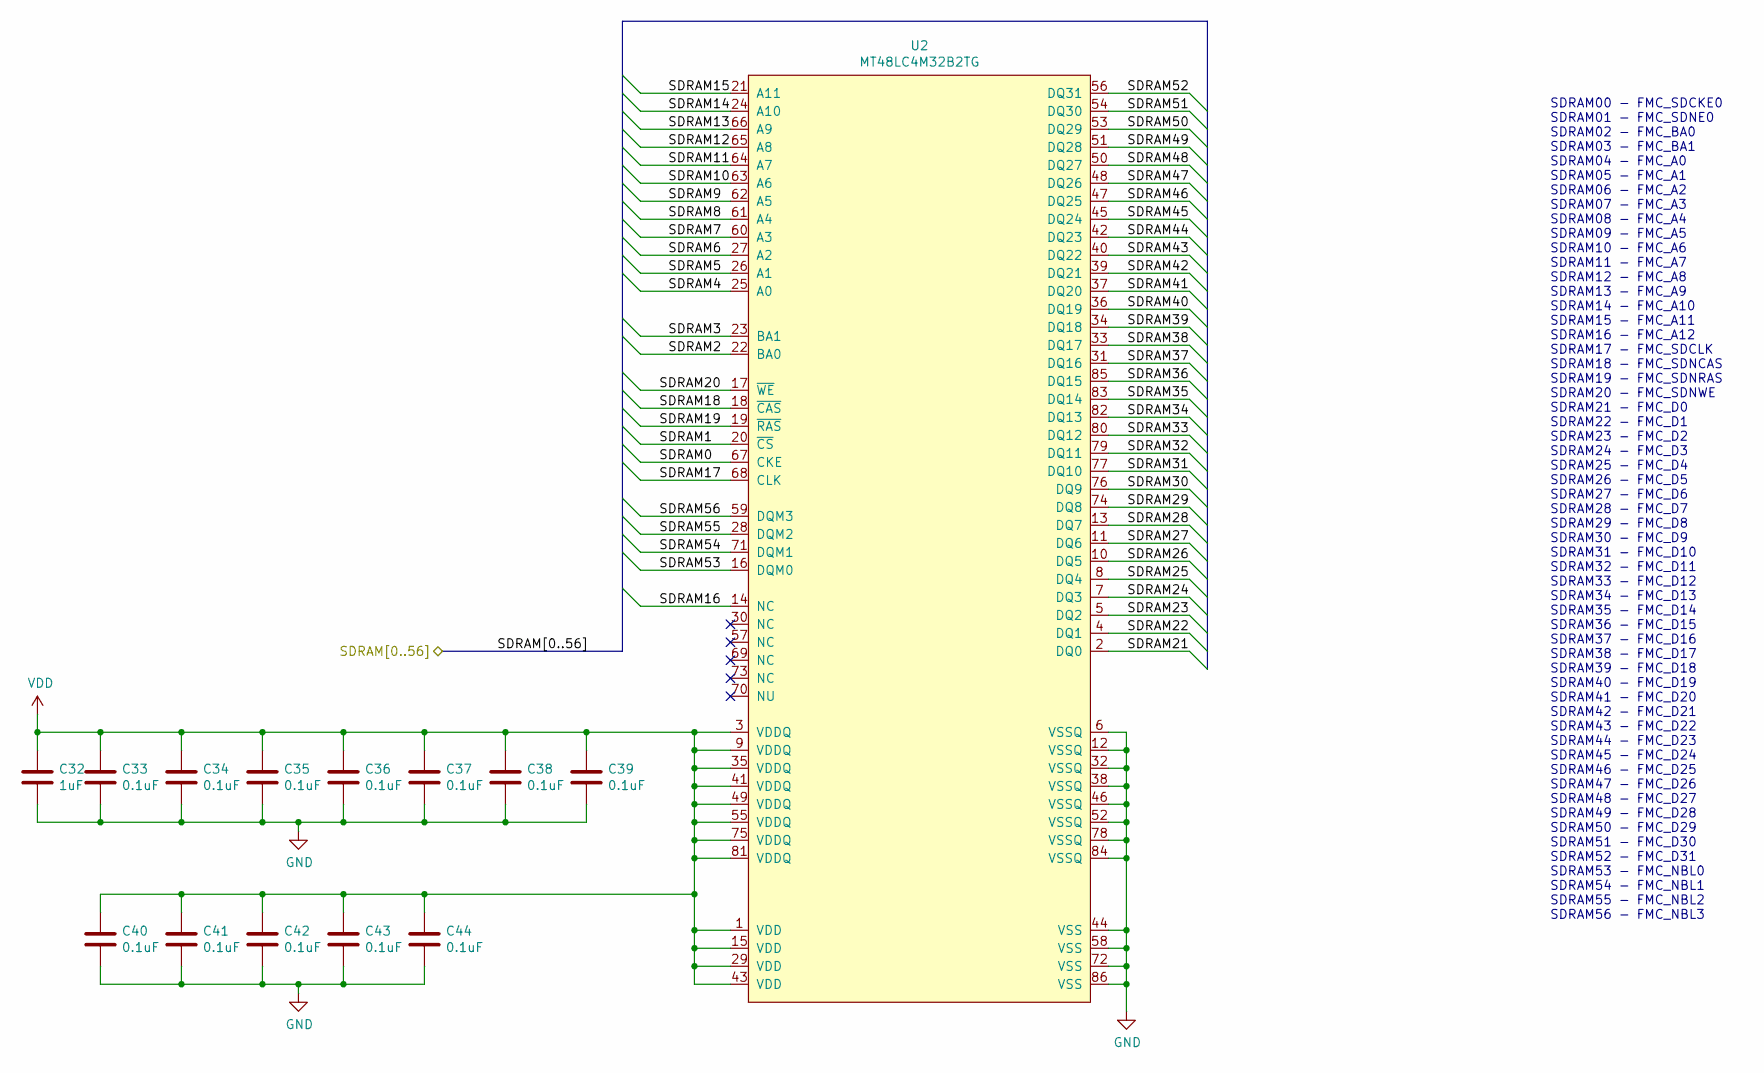
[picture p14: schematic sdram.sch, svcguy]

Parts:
C32: 1uF; C_0402_1005Metric; LCSC C52923
C33, C34, C35, C36, C37, C38, C39, C40, C41, C42, C43, C44: 0.1uF; C_0402_1005Metric; LCSC C1525
U2: MT48LC4M32B2TG; TSOP_II-86-400mill; LCSC C108951

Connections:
/MCU/SDRAM0: U2.67 (CKE); also elsewhere on the board
/MCU/SDRAM1: U2.20 (~CS); also elsewhere on the board
/MCU/SDRAM2: U2.22 (BA0); also elsewhere on the board
/MCU/SDRAM3: U2.23 (BA1); also elsewhere on the board
/MCU/SDRAM4: U2.25 (A0); also elsewhere on the board
/MCU/SDRAM5: U2.26 (A1); also elsewhere on the board
/MCU/SDRAM6: U2.27 (A2); also elsewhere on the board
/MCU/SDRAM7: U2.60 (A3); also elsewhere on the board
/MCU/SDRAM8: U2.61 (A4); also elsewhere on the board
/MCU/SDRAM9: U2.62 (A5); also elsewhere on the board
/MCU/SDRAM10: U2.63 (A6); also elsewhere on the board
/MCU/SDRAM11: U2.64 (A7); also elsewhere on the board
/MCU/SDRAM12: U2.65 (A8); also elsewhere on the board
/MCU/SDRAM13: U2.66 (A9); also elsewhere on the board
/MCU/SDRAM14: U2.24 (A10); also elsewhere on the board
/MCU/SDRAM15: U2.21 (A11); also elsewhere on the board
/MCU/SDRAM16: U2.14 (NC); also elsewhere on the board
/MCU/SDRAM17: U2.68 (CLK); also elsewhere on the board
/MCU/SDRAM18: U2.18 (~CAS); also elsewhere on the board
/MCU/SDRAM19: U2.19 (~RAS); also elsewhere on the board
/MCU/SDRAM20: U2.17 (~WE); also elsewhere on the board
/MCU/SDRAM21: U2.2 (DQ0); also elsewhere on the board
/MCU/SDRAM22: U2.4 (DQ1); also elsewhere on the board
/MCU/SDRAM23: U2.5 (DQ2); also elsewhere on the board
/MCU/SDRAM24: U2.7 (DQ3); also elsewhere on the board
/MCU/SDRAM25: U2.8 (DQ4); also elsewhere on the board
/MCU/SDRAM26: U2.10 (DQ5); also elsewhere on the board
/MCU/SDRAM27: U2.11 (DQ6); also elsewhere on the board
/MCU/SDRAM28: U2.13 (DQ7); also elsewhere on the board
/MCU/SDRAM29: U2.74 (DQ8); also elsewhere on the board
/MCU/SDRAM30: U2.76 (DQ9); also elsewhere on the board
/MCU/SDRAM31: U2.77 (DQ10); also elsewhere on the board
/MCU/SDRAM32: U2.79 (DQ11); also elsewhere on the board
/MCU/SDRAM33: U2.80 (DQ12); also elsewhere on the board
/MCU/SDRAM34: U2.82 (DQ13); also elsewhere on the board
/MCU/SDRAM35: U2.83 (DQ14); also elsewhere on the board
/MCU/SDRAM36: U2.85 (DQ15); also elsewhere on the board
/MCU/SDRAM37: U2.31 (DQ16); also elsewhere on the board
/MCU/SDRAM38: U2.33 (DQ17); also elsewhere on the board
/MCU/SDRAM39: U2.34 (DQ18); also elsewhere on the board
/MCU/SDRAM40: U2.36 (DQ19); also elsewhere on the board
/MCU/SDRAM41: U2.37 (DQ20); also elsewhere on the board
/MCU/SDRAM42: U2.39 (DQ21); also elsewhere on the board
/MCU/SDRAM43: U2.40 (DQ22); also elsewhere on the board
/MCU/SDRAM44: U2.42 (DQ23); also elsewhere on the board
/MCU/SDRAM45: U2.45 (DQ24); also elsewhere on the board
/MCU/SDRAM46: U2.47 (DQ25); also elsewhere on the board
/MCU/SDRAM47: U2.48 (DQ26); also elsewhere on the board
/MCU/SDRAM48: U2.50 (DQ27); also elsewhere on the board
/MCU/SDRAM49: U2.51 (DQ28); also elsewhere on the board
/MCU/SDRAM50: U2.53 (DQ29); also elsewhere on the board
/MCU/SDRAM51: U2.54 (DQ30); also elsewhere on the board
/MCU/SDRAM52: U2.56 (DQ31); also elsewhere on the board
/MCU/SDRAM53: U2.16 (DQM0); also elsewhere on the board
/MCU/SDRAM54: U2.71 (DQM1); also elsewhere on the board
/MCU/SDRAM55: U2.28 (DQM2); also elsewhere on the board
/MCU/SDRAM56: U2.59 (DQM3); also elsewhere on the board
GND: C32.2, C33.2, C34.2, C35.2, C36.2, C37.2, C38.2, C39.2, C40.2, C41.2, C42.2, C43.2, C44.2, U2.6 (VSSQ), U2.12 (VSSQ), U2.32 (VSSQ), U2.38 (VSSQ), U2.44 (VSS), U2.46 (VSSQ), U2.52 (VSSQ), U2.58 (VSS), U2.72 (VSS), U2.78 (VSSQ), U2.84 (VSSQ), U2.86 (VSS); also elsewhere on the board
VDD: C32.1, C33.1, C34.1, C35.1, C36.1, C37.1, C38.1, C39.1, C40.1, C41.1, C42.1, C43.1, C44.1, U2.1 (VDD), U2.3 (VDDQ), U2.9 (VDDQ), U2.15 (VDD), U2.29 (VDD), U2.35 (VDDQ), U2.41 (VDDQ), U2.43 (VDD), U2.49 (VDDQ), U2.55 (VDDQ), U2.75 (VDDQ), U2.81 (VDDQ); also elsewhere on the board

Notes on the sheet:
SDRAM00 - FMC_SDCKE0 SDRAM01 - FMC_SDNE0 SDRAM02 - FMC_BA0 SDRAM03 - FMC_BA1 SDRAM04 - FMC_A0 SDRAM05 - FMC_A1 SDRAM06 - FMC_A2 SDRAM07 - FMC_A3 SDRAM08 - FMC_A4 SDRAM09 - FMC_A5 SDRAM10 - FMC_A6 SDRAM11 - FMC_A7 SDRAM12 - FMC_A8 SDRAM13 - FMC_A9 SDRAM14 - FMC_A10 SDRAM15 - FMC_A11 SDRAM16 - FMC_A1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

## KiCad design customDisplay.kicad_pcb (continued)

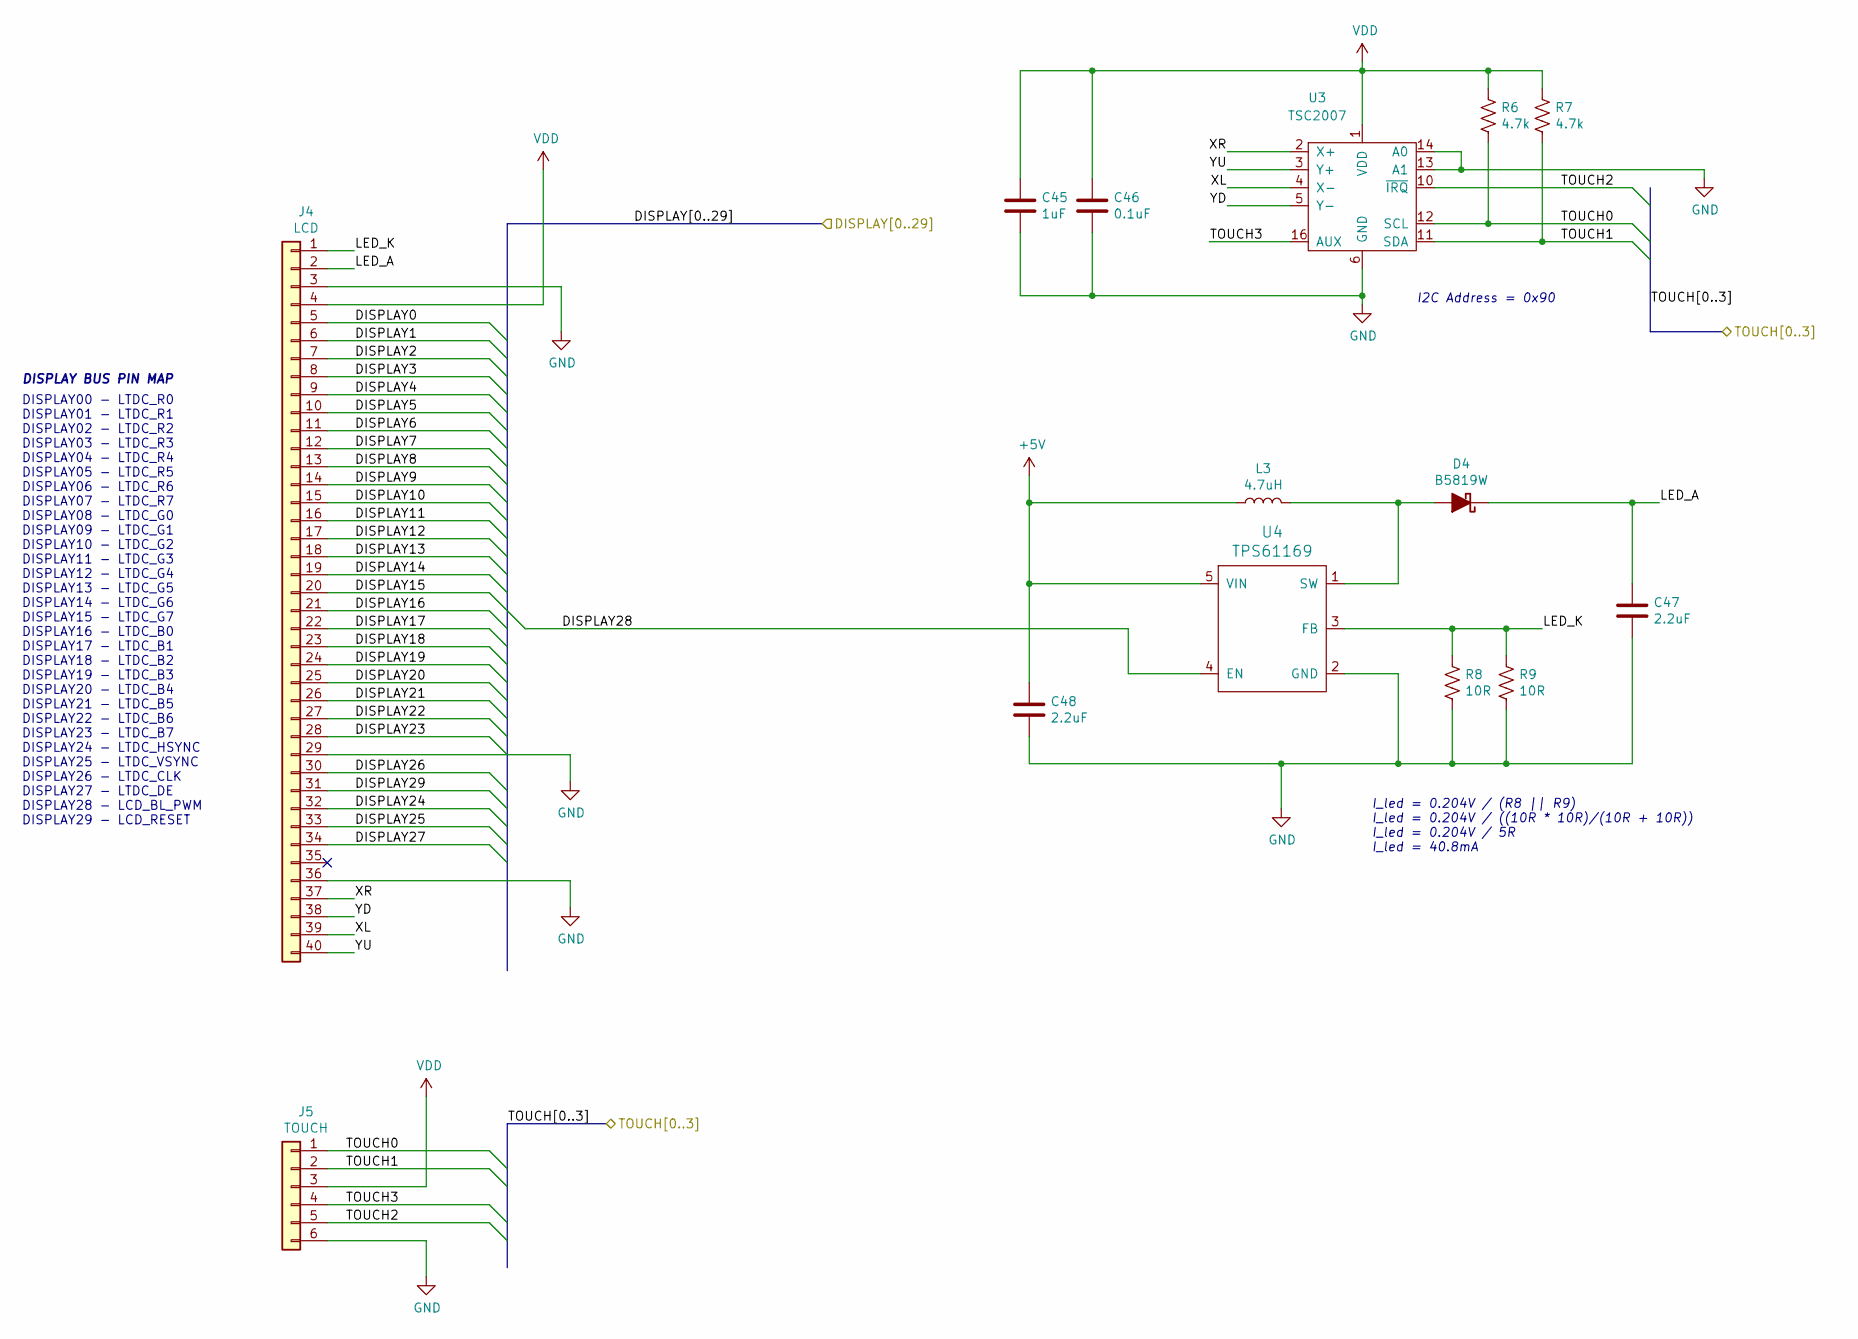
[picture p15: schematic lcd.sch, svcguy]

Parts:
C45: 1uF; C_0402_1005Metric; LCSC C52923
C46: 0.1uF; C_0402_1005Metric; LCSC C1525
C47, C48: 2.2uF; C_0603_1608Metric; LCSC C23630
D4: B5819W; D_SOD-123; LCSC C8598
J4: LCD; FH12A-40S-0.5SH_REVERSE_PIN_NUMBERING; LCSC C262686
J5: TOUCH; Hirose_FH12-6S-0.5SH_1x06-1MP_P0.50mm_Horizontal; LCSC C262287
L3: 4.7uH; MWSA0402; LCSC C408337
R6, R7: 4.7k; R_0402_1005Metric; LCSC C25900
R8, R9: 10R; R_1206_3216Metric; LCSC C17903
U3: TSC2007; HTSSOP-16-1EP_4.4x5mm_P0.65mm_EP3x3mm; LCSC C38398
U4: TPS61169; SC70; LCSC C71045

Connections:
+5V: C48.1, L3.1, U4.5 (VIN); also elsewhere on the board
/LCD/DISPLAY0: J4.5; also elsewhere on the board
/LCD/DISPLAY1: J4.6; also elsewhere on the board
/LCD/DISPLAY2: J4.7; also elsewhere on the board
/LCD/DISPLAY3: J4.8; also elsewhere on the board
/LCD/DISPLAY4: J4.9; also elsewhere on the board
/LCD/DISPLAY5: J4.10; also elsewhere on the board
/LCD/DISPLAY6: J4.11; also elsewhere on the board
/LCD/DISPLAY7: J4.12; also elsewhere on the board
/LCD/DISPLAY8: J4.13; also elsewhere on the board
/LCD/DISPLAY9: J4.14; also elsewhere on the board
/LCD/DISPLAY10: J4.15; also elsewhere on the board
/LCD/DISPLAY11: J4.16; also elsewhere on the board
/LCD/DISPLAY12: J4.17; also elsewhere on the board
/LCD/DISPLAY13: J4.18; also elsewhere on the board
/LCD/DISPLAY14: J4.19; also elsewhere on the board
/LCD/DISPLAY15: J4.20; also elsewhere on the board
/LCD/DISPLAY16: J4.21; also elsewhere on the board
/LCD/DISPLAY17: J4.22; also elsewhere on the board
/LCD/DISPLAY18: J4.23; also elsewhere on the board
/LCD/DISPLAY19: J4.24; also elsewhere on the board
/LCD/DISPLAY20: J4.25; also elsewhere on the board
/LCD/DISPLAY21: J4.26; also elsewhere on the board
/LCD/DISPLAY22: J4.27; also elsewhere on the board
/LCD/DISPLAY23: J4.28; also elsewhere on the board
/LCD/DISPLAY24: J4.32; also elsewhere on the board
/LCD/DISPLAY25: J4.33; also elsewhere on the board
/LCD/DISPLAY26: J4.30; also elsewhere on the board
/LCD/DISPLAY27: J4.34; also elsewhere on the board
/LCD/DISPLAY28: U4.4 (EN); also elsewhere on the board
/LCD/DISPLAY29: J4.31; also elsewhere on the board
/LCD/LED_A: C47.1, D4.1 (K), J4.2
/LCD/LED_K: J4.1, R8.1, R9.1, U4.3 (FB)
/LCD/TOUCH2: J5.5, U3.10 (~IRQ); also elsewhere on the board
/LCD/TOUCH3: J5.4, U3.16 (AUX); also elsewhere on the board
/LCD/XL: J4.39, U3.4 (X-)
/LCD/XR: J4.37, U3.2 (X+)
/LCD/YD: J4.38, U3.5 (Y-)
/LCD/YU: J4.40, U3.3 (Y+)
/TOUCH0: J5.1, R6.2, U3.12 (SCL); also elsewhere on the board
/TOUCH1: J5.2, R7.2, U3.11 (SDA); also elsewhere on the board
GND: C45.2, C46.2, C47.2, C48.2, J4.3, J4.29, J4.36, J5.6, R8.2, R9.2, U3.6 (GND), U3.13 (A1), U3.14 (A0), U3.17, U4.2 (GND); also elsewhere on the board
unnamed: D4.2 (A), L3.2, U4.1 (SW)
VDD: C45.1, C46.1, J4.4, J5.3, R6.1, R7.1, U3.1 (VDD); also elsewhere on the board

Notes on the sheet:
DISPLAY BUS PIN MAP
DISPLAY00 - LTDC_R0 DISPLAY01 - LTDC_R1 DISPLAY02 - LTDC_R2 DISPLAY03 - LTDC_R3 DISPLAY04 - LTDC_R4 DISPLAY05 - LTDC_R5 DISPLAY06 - LTDC_R6 DISPLAY07 - LTDC_R7 DISPLAY08 - LTDC_G0 DISPLAY09 - LTDC_G1 DISPLAY10 - LTDC_G2 DISPLAY11 - LTDC_G3 DISPLAY12 - LTDC_G4 DISPLAY13 - LTDC_G5 DISPLAY14 - LTDC_G6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
I_led = 0.204V / (R8 || R9) I_led = 0.204V / ((10R * 10R)/(10R + 10R)) I_led = 0.204V / 5R I_led = 40.8mA
I2C Address = 0x90

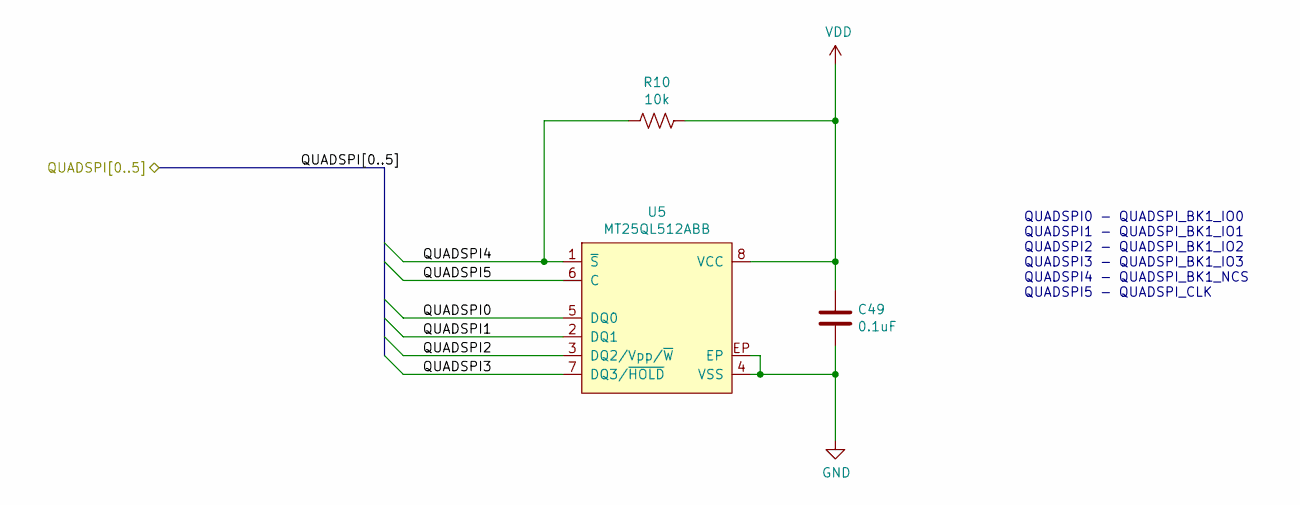
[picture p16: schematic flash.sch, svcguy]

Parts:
C49: 0.1uF; C_0402_1005Metric; LCSC C1525
R10: 10k; R_0402_1005Metric; LCSC C25744
U5: MT25QL512ABB; W-PDFN-8; LCSC C88868

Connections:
/Flash/QUADSPI0: U5.5 (DQ0); also elsewhere on the board
/Flash/QUADSPI1: U5.2 (DQ1); also elsewhere on the board
/Flash/QUADSPI2: U5.3 (DQ2/Vpp/~W); also elsewhere on the board
/Flash/QUADSPI3: U5.7 (DQ3/~HOLD); also elsewhere on the board
/Flash/QUADSPI4: R10.2, U5.1 (~S); also elsewhere on the board
/Flash/QUADSPI5: U5.6 (C); also elsewhere on the board
GND: C49.2, U5.4 (VSS), U5.12, U5.EP; also elsewhere on the board
VDD: C49.1, R10.1, U5.8 (VCC); also elsewhere on the board

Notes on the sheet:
QUADSPI0 - QUADSPI_BK1_IO0 QUADSPI1 - QUADSPI_BK1_IO1 QUADSPI2 - QUADSPI_BK1_IO2 QUADSPI3 - QUADSPI_BK1_IO3 QUADSPI4 - QUADSPI_BK1_NCS QUADSPI5 - QUADSPI_CLK

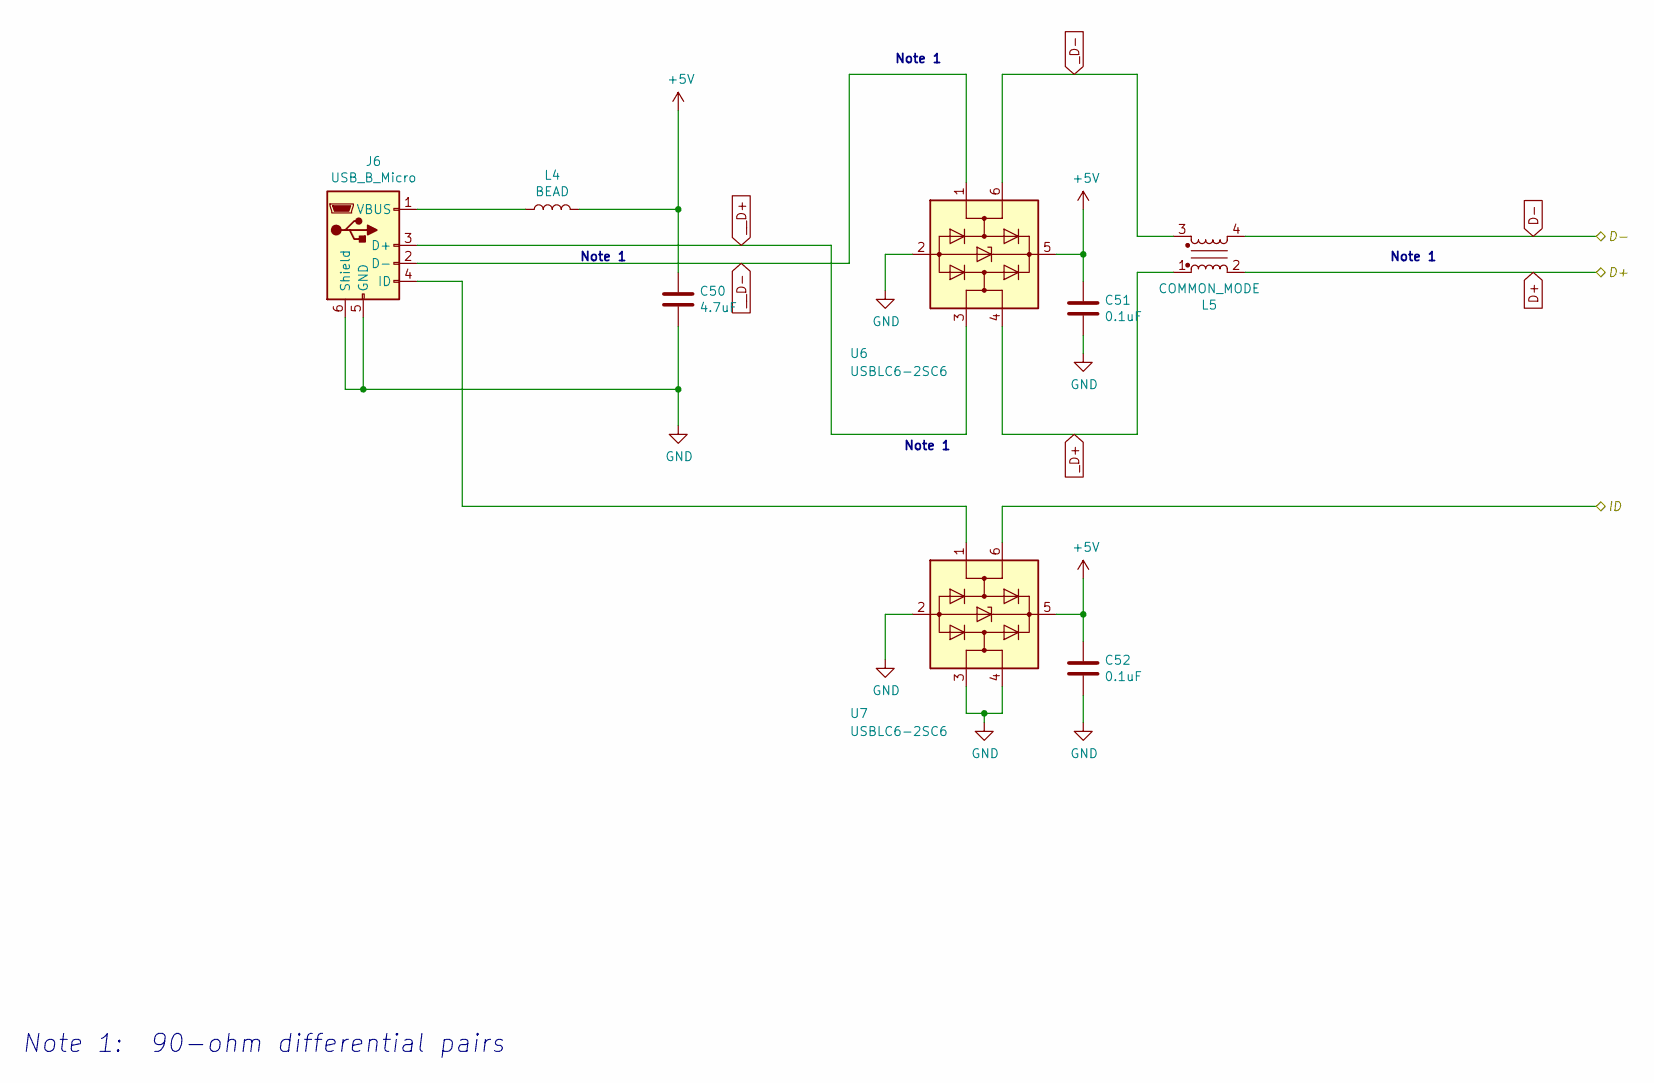
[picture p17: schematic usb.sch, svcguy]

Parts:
C50: 4.7uF; C_0805_2012Metric; LCSC C1779
C51, C52: 0.1uF; C_0402_1005Metric; LCSC C1525
J6: USB_B_Micro; USB_Micro-B_Amphenol_10103594-0001LF_Horizontal; LCSC C428495
L4: BEAD; L_0805_2012Metric; LCSC C1015
L5: COMMON_MODE; COMMON_MODE_FILTER_0805; LCSC C54888
U6, U7: USBLC6-2SC6; SOT-23-6; LCSC C7519

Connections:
+5V: C50.1, C51.1, C52.1, L4.2, U6.5 (VBUS), U7.5 (VBUS); also elsewhere on the board
/USB/ID: U7.6 (I/O1); also elsewhere on the board
D+: L5.2; also elsewhere on the board
D-: L5.4; also elsewhere on the board
GND: C50.2, C51.2, C52.2, J6.5 (GND), J6.6 (Shield), U6.2 (GND), U7.2 (GND), U7.3 (I/O2), U7.4 (I/O2); also elsewhere on the board
unnamed: J6.1 (VBUS), L4.1
unnamed: J6.4 (ID), U7.1 (I/O1)
_D+: L5.1, U6.4 (I/O2)
_D-: L5.3, U6.6 (I/O1)
__D+: J6.3 (D+), U6.3 (I/O2)
__D-: J6.2 (D-), U6.1 (I/O1)

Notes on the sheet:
Note 1
Note 1: 90-ohm differential pairs

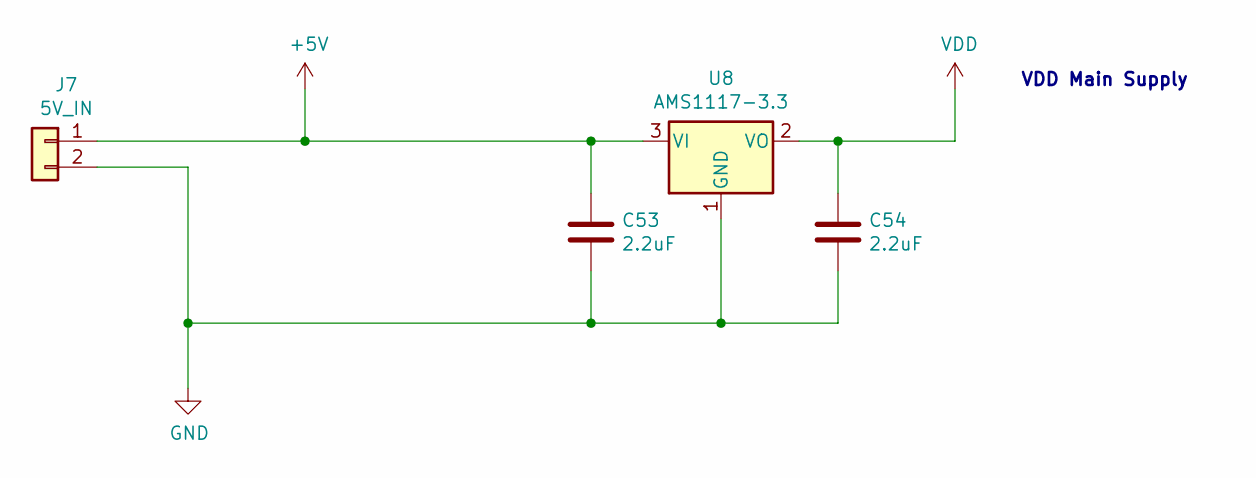
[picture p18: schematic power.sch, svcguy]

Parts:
C53, C54: 2.2uF; C_0603_1608Metric; LCSC C23630
J7: 5V_IN; PinHeader_1x02_P2.54mm_Vertical; LCSC DNP
U8: AMS1117-3.3; SOT-223-3_TabPin2; LCSC C6186

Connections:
+5V: C53.1, J7.1, U8.3 (VI); also elsewhere on the board
GND: C53.2, C54.2, J7.2, U8.1 (GND); also elsewhere on the board
VDD: C54.1, U8.2 (VO); also elsewhere on the board

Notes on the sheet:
VDD Main Supply

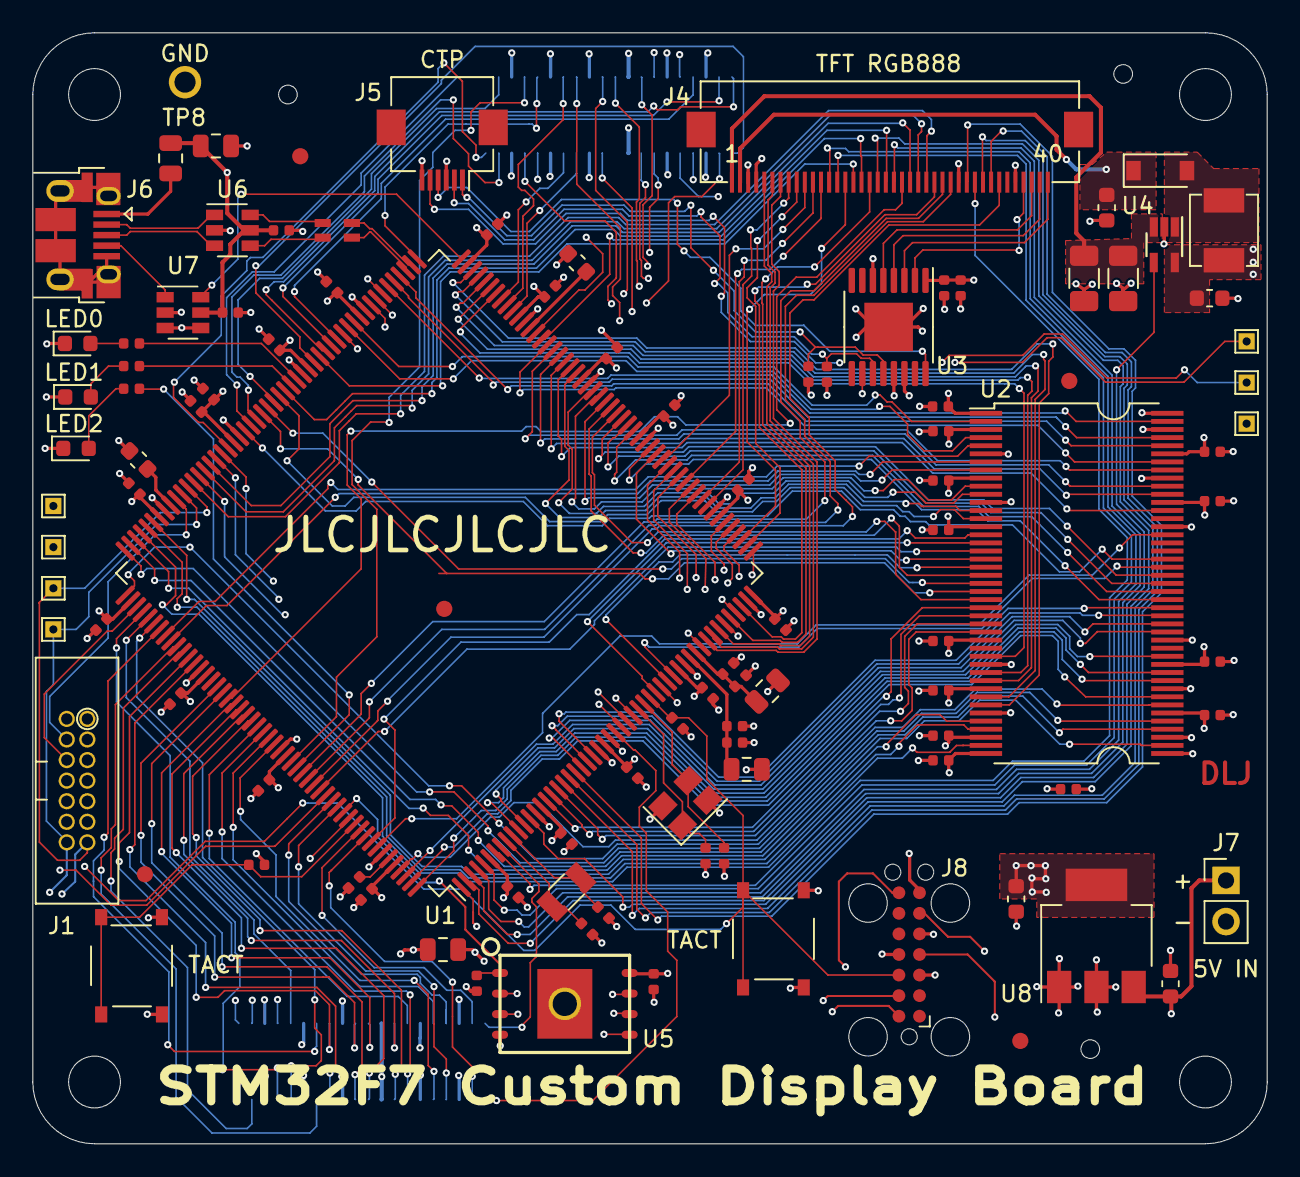
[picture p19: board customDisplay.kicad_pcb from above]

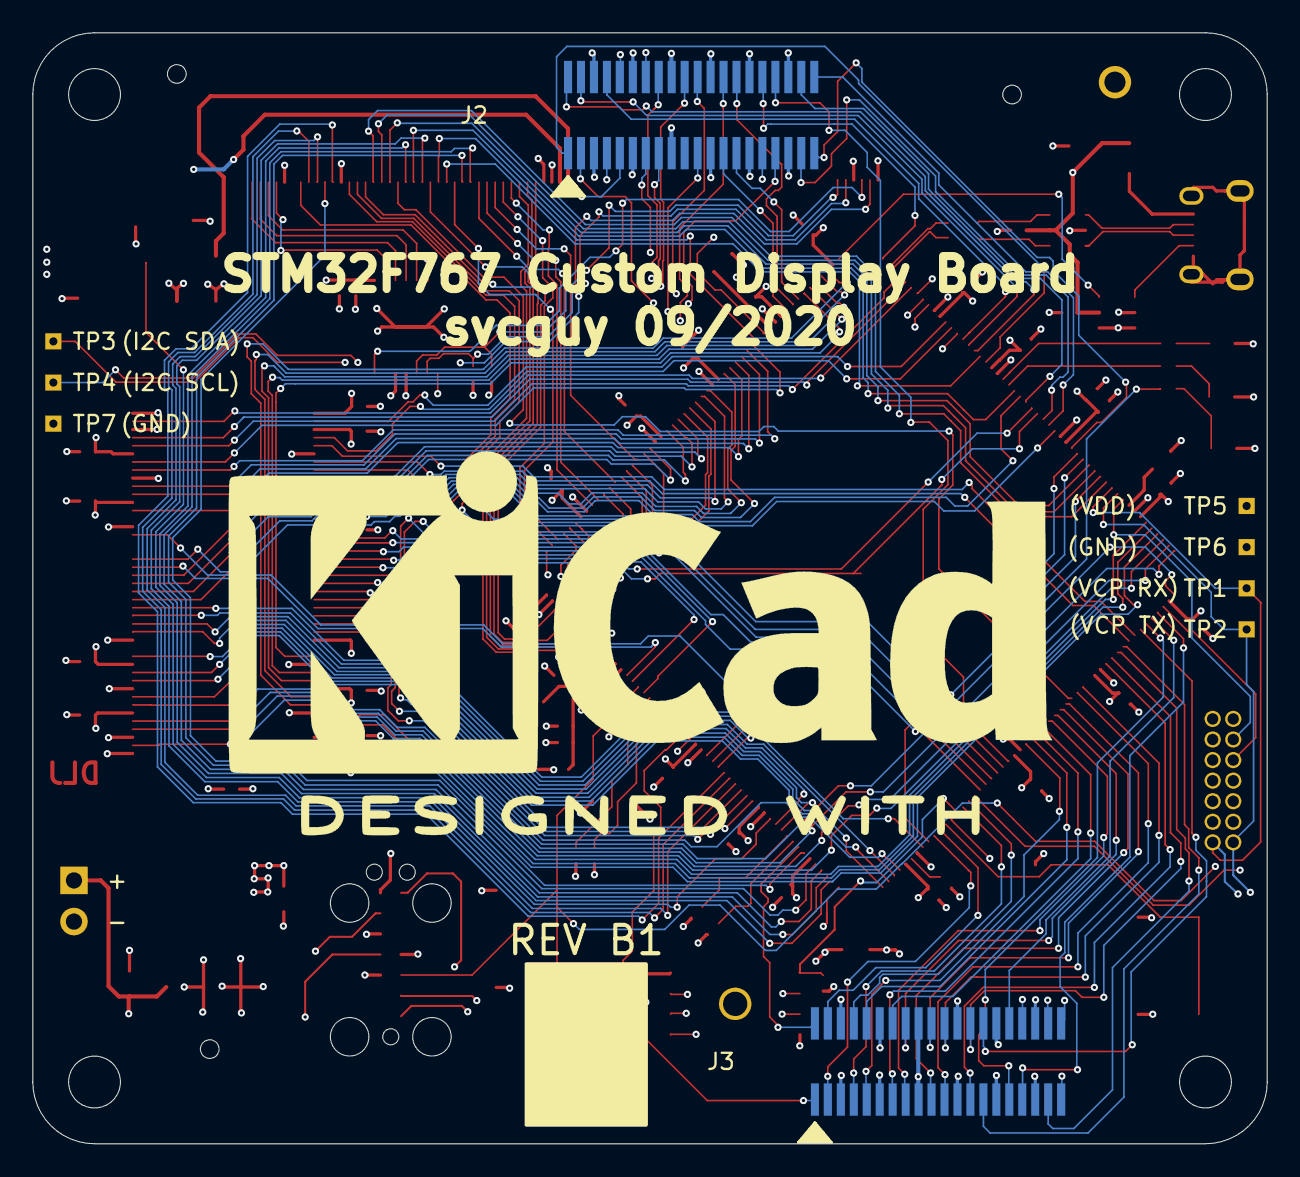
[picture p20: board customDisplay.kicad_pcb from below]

Board: 4 copper layers, 76.2 x 68.6 mm, 113 parts (2 on the bottom side), 193 nets.

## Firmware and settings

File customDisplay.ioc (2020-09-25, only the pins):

Mcu.UserName=STM32F767BGTx
PA1.Signal=LTDC_R2
PA10.Signal=LTDC_B4
PA11.GPIO_Label=VCP_RX
PA11.Signal=UART4_RX
PA12.GPIO_Label=VCP_TX
PA12.Signal=UART4_TX
PA13.Signal=SYS_JTMS-SWDIO
PA14.Signal=SYS_JTCK-SWCLK
PA2.Signal=LTDC_R1
PA3.Signal=LTDC_B5
PA5.Signal=LTDC_R4
PA6.Signal=LTDC_G2
PA8.Signal=LTDC_B3
PB0.Signal=LTDC_R3
PB1.Signal=LTDC_R6
PB10.Signal=LTDC_G4
PB12.Signal=USB_OTG_HS_ID
PB14.Signal=USB_OTG_HS_DM
PB15.Signal=USB_OTG_HS_DP
PB3.Signal=SYS_JTDO-SWO
PB6.Signal=QUADSPI_BK1_NCS
PC0.Signal=FMC_SDNWE
PC14/OSC32_IN.Signal=RCC_OSC32_IN
PC15/OSC32_OUT.Signal=RCC_OSC32_OUT
PC2.Signal=FMC_SDNE0
PC3.Signal=FMC_SDCKE0
PC9.Signal=LTDC_B2
PD0.Signal=FMC_D2_DA2
PD1.Signal=FMC_D3_DA3
PD10.Signal=FMC_D15_DA15
PD11.GPIO_Label=TOUCH_INT
PD11.Signal=GPXTI11
PD12.Signal=I2C4_SCL
PD13.Signal=I2C4_SDA
PD14.Signal=FMC_D0_DA0
PD15.Signal=FMC_D1_DA1
PD8.Signal=FMC_D13_DA13
PD9.Signal=FMC_D14_DA14
PE0.Signal=FMC_NBL0
PE1.Signal=FMC_NBL1
PE10.Signal=FMC_D7_DA7
PE11.Signal=FMC_D8_DA8
PE12.Signal=FMC_D9_DA9
PE13.Signal=FMC_D10_DA10
PE14.Signal=FMC_D11_DA11
PE15.Signal=FMC_D12_DA12
PE2.Signal=QUADSPI_BK1_IO2
PE4.Signal=LTDC_B0
PE5.Signal=LTDC_G0
PE6.Signal=LTDC_G1
PE7.Signal=FMC_D4_DA4
PE8.Signal=FMC_D5_DA5
PE9.Signal=FMC_D6_DA6
PF0.Signal=FMC_A0
PF1.Signal=FMC_A1
PF10.Signal=QUADSPI_CLK
PF11.Signal=FMC_SDNRAS
PF12.Signal=FMC_A6
PF13.Signal=FMC_A7
PF14.Signal=FMC_A8
PF15.Signal=FMC_A9
PF2.Signal=FMC_A2
PF3.Signal=FMC_A3
PF4.Signal=FMC_A4
PF5.Signal=FMC_A5
PF6.Signal=QUADSPI_BK1_IO3
PF8.Signal=QUADSPI_BK1_IO0
PF9.Signal=QUADSPI_BK1_IO1
PG0.Signal=FMC_A10
PG1.Signal=FMC_A11
PG15.Signal=FMC_SDNCAS
PG4.Signal=FMC_A14_BA0
PG5.Signal=FMC_A15_BA1
PG8.Signal=FMC_SDCLK
PH0/OSC_IN.Signal=RCC_OSC_IN
PH1/OSC_OUT.Signal=RCC_OSC_OUT
PH10.Signal=FMC_D18
PH11.Signal=FMC_D19
PH12.Signal=FMC_D20
PH13.Signal=FMC_D21
PH14.Signal=FMC_D22
PH15.Signal=FMC_D23
PH2.Signal=LTDC_R0
PH4.Signal=LTDC_G5
PH8.Signal=FMC_D16
PH9.Signal=FMC_D17
PI0.Signal=FMC_D24
PI1.Signal=FMC_D25
PI10.Signal=FMC_D31
PI11.Signal=LTDC_G6
PI12.Signal=LTDC_HSYNC
PI13.Signal=LTDC_VSYNC
PI14.Signal=LTDC_CLK
PI2.Signal=FMC_D26
PI3.Signal=FMC_D27
PI4.Signal=FMC_NBL2
PI5.Signal=FMC_NBL3
PI6.Signal=FMC_D28
PI7.Signal=FMC_D29
PI9.Signal=FMC_D30
PJ0.Signal=LTDC_R7
PJ10.Signal=LTDC_G3
PJ13.Signal=LTDC_B1
PJ4.Signal=LTDC_R5
PK0.GPIO_Label=LED0
PK0.Signal=GPIO_Output
PK1.GPIO_Label=LED1
PK1.Signal=GPIO_Output
PK2.Signal=LTDC_G7
PK5.Signal=LTDC_B6
PK6.Signal=LTDC_B7
PK7.Signal=LTDC_DE
